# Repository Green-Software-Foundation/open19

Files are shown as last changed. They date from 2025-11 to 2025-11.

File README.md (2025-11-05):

# Open19 V1 Specification

The Open19 specification is a standard for data center rack and server form factors that focuses on standardized power distribution, high-performance networking, and blind-mate connectors. Key features include multiple server "brick" form factors, a modular power shelf, and support for both traditional air-cooling and newer liquid-cooling systems. It allows vendors to choose their own components while ensuring physical compatibility within the rack, promoting choice and innovation. 

- [Open19-V1-Servers-specification](https://github.com/Green-Software-Foundation/open19/blob/v1.0/discussion-docs/Open19_V1_System_Level_Specification.pdf)
- [Open19_V1_System_Level_Specification](https://github.com/Green-Software-Foundation/open19/blob/v1.0/discussion-docs/Open19_V1_System_Level_Specification.pdf)
***
## Key aspects of the Open19 specification:
Brick form factors: The standard defines several independent server "brick" form factors, including half-width 1U, full-width 1U, 2U, and a half-width 2U for GPUs.

***
### Power:
The system uses a modular power shelf that holds vendor-specific power supplies.
The Open19 v2 specification enables higher power delivery (3.5kW per brick) and supports 48V native power, which is more efficient than traditional 12V systems.
Power and data connectors are designed to be "blind-mate," meaning they connect automatically when a brick is installed, simplifying installation.

***
### Networking:
The baseline connectivity is 100 gigabits per second, which can be extended to 200 gigabits per second.
Future versions are designed to support higher speeds.

***
### Cooling:
The standard supports both traditional air-cooling and newer liquid-cooling systems.
Liquid-cooled racks use blind-mate plumbing connections for coolant, making liquid-cooled server installation as easy as air-cooled ones.

***
### Flexibility:
Open19 only specifies the physical and power/network infrastructure, not the internal components like CPUs or RAM. This allows vendors to choose their own processors and other internal hardware, promoting vendor choice.
Vendors can create and protect their intellectual property without sharing designs via an open-source license.

***
**All documentation associated with a project must be licensed under either a Creative Commons Attribution lincense (CC-BY) or, in the case of technical specifications, under a Creative Commons Attribution NoDerivs license (CC-BY-ND)**

***
***
# Open19 V2 Specification

The Open19 V2 specification, published in December 2023 by the Sustainable & Scalable Infrastructure Alliance (SSIA) under the Linux Foundation, introduces significant updates primarily focused on higher power densities, a native 48V DC power solution, and a standardized liquid cooling system. 
***
## Key updates and changes from V1 include:

### Liquid Cooling Standard: 
V2 incorporates a pluggable liquid cooling standard with blind-mate connectors, making the installation of liquid-cooled servers as simple as air-cooled equipment and eliminating external plumbing after initial setup.
***
### Power Distribution: 
The specification moves to a native 48V DC power solution from the 12V DC in V1. This is more efficient for modern data centers and aligns Open19 with other industry standards like OCP, allowing server manufacturers to adopt a single standard.
***
### Increased Power Density: 
The power delivery per "brick" (a half-width 1U server unit) is significantly increased. V1 offered 400W per brick, while V2 increases this capacity to support up to 3.5kW per brick (or 1.6kW per 1RU section), accommodating the demands of next-generation processors and AI workloads.

### Enhanced Connectivity: 
Network bandwidth per server is enhanced, with initial support for 50GbE connectivity per brick, and a path to 200GbE in the future.
***
### Simplified Cabling: 
The design continues to use blind-mate connectors for power and data, further minimizing or eliminating the need for complex, manual cabling at the rear of the rack during server installation.
Backward Compatibility: The new specification maintains the original 19-inch form factor and core principles, allowing for backward compatibility so that V1 servers can still be used in the new V2 system

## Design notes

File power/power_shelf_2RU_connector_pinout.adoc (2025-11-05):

= 2RU Power Shelf connector pinout

In a 2RU power shelf, the following table describes the grouping for four power connector sets. Rows A, B are the bottom RU of a power shelf. Rows C, D are the upper RU of a power shelf. When viewing the rear of the power shelf from the outside, column C1 is on the left and column C16 is on the right.

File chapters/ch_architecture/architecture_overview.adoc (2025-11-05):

ifndef::imagesdir[:imagesdir: ../../images]

ifndef::book[]

endif::[]

= Open19 Architecture Overview

== General

This document will introduce the Open19 V2 architecture, built upon many of the original Open19 principles (referred to as Open19 V1). The significant changes from the V1 specification are:

- Introduction of liquid cooling solutions in both single-phase and two-phase
- Introduction of 48V DC power with no V1 interop
- Increase in differential pairs for high-speed data with support for 56G PAM-4
- Definition of a 4U brick cage

The building blocks can be used to assemble working solutions, which can adapt to site-specific requirements. "Paved path" solutions are detailed in the implementers guide(s).

The only "hard" requirement for Open19 is 1000mm deep 19" racks.

== Background

The Open19 specification defines a consistent mechanical standard for technology delivery. It addresses the operational complexity of standard 19" servers while maintaining an envelop to retain IP. Finally, it de-couples the infrastructure components from the technology allowing for extended life-cycles to meet sustainability goals. Open19 V2 builds on the foundational architecture of the original specification (retroactively termed Open19 V1).

== Requirements

Open19 maintains a minimal set of requirements:

- Commodity EIA/TIA 19" square-hold 4-post rack. The rack is not defined; any EIA/TIA compatible rack able to support the final weight AND at least 1000mm deep can be used.
- 10&#0176;C to 40&#0176;C ambient environment, in line with ASHRAE A1A
- Water supply temperate meeting ASHRAE W27
- Single-phase or three-phase AC power available world-wide in 50/60Hz and 380V HVDC

Open19 V2 explicitly does NOT define a number of areas:

- Rack height, depth, nor width
- Rack level infrastructure including HRU/CDU's, rack coolant manifolds, power strips, and network switches.
- Technology and cooling delivered inside the brick.

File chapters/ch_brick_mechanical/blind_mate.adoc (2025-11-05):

ifndef::imagesdir[:imagesdir: ../../images]
ifndef::brick[:brick: brick]
ifndef::UBrick[:UBrick: Brick]
ifndef::brickplus[:brickplus: brick]
:xrefstyle: full

= Blind mate interfaces

A {brick} is equipped with at least one set of blind mate connectors for receiving +48V DC power and transferring data with an external device, typically a network switch. Introduced in this version is are blind mate connections to facilitate liquid cooling. The connections mate with cable and manifold projections from the rear wall of the cage.

- Power connector: Molex Ten60 PN: 220370-0001 (35A) 22037-0000 (70A), refer to Molex document link:../../power/2203700000psd000_01__4_.pdf[PSD-220370-0000]

- Data connector: Molex 4x8 Impel with guide receptacle PN: 204066-9038 (PCB thickness 2.2-4.1mm), 204066-9138 (PCB thickness 1.0-1.9mm), refer to Molex document link:../../data/2040669001-sdpsd000_02[PSD-204066-9001]

The power connector has two ratings:

- Power: Not-To-Exceed (NTE) 70A at +48V DC
- Power: Not-To-Exceed (NTE) 35A at +48V DC

The ratings shall be coordinated with the power shelf. 35A bricks shall be enabled in 70A capable infrastructure. 70A bricks are keyed to prevent unsafe operation in 35A infrastructure.

ifdef::dhhw,shdw[]
The {brick} may populate a second set of connectors, as required.
endif::[]

ifdef::dhdw[]
The {brick} may populate up to four sets of connectors, as required.
endif::[]

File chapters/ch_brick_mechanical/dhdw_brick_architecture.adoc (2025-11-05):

ifndef::imagesdir[:imagesdir: ../../images]
ifndef::brick[:brick: double high double wide brick]
ifndef::UBrick[:UBrick: Double high double wide brick]
ifndef::brickplus[:brickplus: double high double wide]
:bricktype: dhdw
:dhdw:
:feedcount: 4
:chapter:
:xrefstyle: full

ifdef::standalone[]
:sectnums:
:toc: macro 

= {Ubrick} Mechanical Specification [DHHW]
Linux Foundation Open19 Project
:title-page-background-image: 

toc::[]

<<<
[preface]

include::../book/contributors.adoc[]

<<<

[preface]
== Change log

|===
| Author | Date | Version | Change Details 
| My Truong | Nov 2023 | 2.0 | Liquid-cooled Spec release
| My Truong | Nov 2022 | RC 3 | Power connector move towards liquid cooling cutout 
| My Truong | Oct 2022  | RC2 | Power connector offset correction, 2P liquid cooling connector update 
| My Truong | Sept 2022 | RC1 | 48V DC @70A, 4x8 data connector, liquid cooling 
|===
endif::[]

<<<

ifndef::standalone[]
= {Ubrick} Mechanical Specification [DHDW]

endif::[]
== DHDW {ubrick}

:leveloffset: +1

The DHDW {brickplus} is commonly used as a 2U server form-factor.

<<<

include::../../mechanical/brick/Brick_Dimensions.adoc[]

:leveloffset: -1

<<<

== Mechanical features

:leveloffset: +2

include::retention.adoc[]

include::mechanical_guide.adoc[]

ifdef::liquid[]
include::mechanical_assist.adoc[]
endif::[]

include::mechanical_key.adoc[]

include::pcba.adoc[]

include::materials.adoc[]

include::blind_mate.adoc[]

:leveloffset: -2

=== Weight

The maximum weight of the brick, when equipped with all drives and/or accessories, is 120lbs (54.43kg). This is an increase of 20lbs from V1.

== Connector Pinout

:leveloffset: +2

include::../../power/brick_power.adoc[]

include::../../data/data_connector.adoc[]

include::../../data/ethernet_interop.adoc[]

:leveloffset: -2

<<<
ifdef::liquid[]
== Liquid cooling

:leveloffset: +2

include::brick_liquid_cooling.adoc[]

:leveloffset: -2

<<<
endif::[]
== Design guidance

Design guidance is not a specification requirement. It is simple design guidance that can be implemented to simplify future needs, to meet certification requirements, or satisfy general fit & finish.

=== {UBrick} faceplate guidance 

The faceplate is notched above and below the fastener (See <<#img-dhdw-brick-retention>>). Note that the faceplate can accommodate any type of ports or drives as needed and is not required to be fully perforated.

Screws and/or rivets used to secure the top cover are flush to be under-flush. The vertical edges on the rear of the brick chassis base are coined to break sharp edges.

=== Back panel safety perforation

See below for typical dimensions of the airflow perforation. All dimensions below are critical.

[#img-panel-perforation]
.{UBrick} panel perforation



{sp} +

:leveloffset: +3

include::keepout.adoc[]

:leveloffset: -3

<<<

== Brick performance

:leveloffset: +2

include::../../power/brick_startup.adoc[]

:leveloffset: -2

<<<

ifdef::standalone[]

include::../book/appendix.adoc[]

endif::[]

:!dhdw:
:!feedcount:

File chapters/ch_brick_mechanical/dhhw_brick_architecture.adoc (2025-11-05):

ifndef::imagesdir[:imagesdir: ../../images]
ifndef::brick[:brick: double high half width brick]
ifndef::UBrick[:UBrick: Double high half width brick]
ifndef::brickplus[:brickplus: double high half width]
:bricktype: dhhw
:dhhw:
:feedcount: 2
:chapter:
:xrefstyle: full

ifdef::standalone[]
:sectnums:
:toc: macro 

= {Ubrick} Mechanical Specification [DHHW]
Linux Foundation Open19 Project
:title-page-background-image: 

toc::[]

<<<
[preface]

include::../book/contributors.adoc[]

<<<

[preface]
== Change log

|===
| Author | Date | Version | Change Details 
| My Truong | Nov 2023 | 2.0 | Liquid-cooled Spec release
| My Truong | Nov 2022 | RC 3 | Power connector move towards liquid cooling cutout 
| My Truong | Oct 2022  | RC2 | Power connector offset correction, 2P liquid cooling connector update 
| My Truong | Sept 2022 | RC1 | 48V DC @70A, 4x8 data connector, liquid cooling 
|===
endif::[]

<<<

ifndef::standalone[]
= {Ubrick} Mechanical Specification [DHHW]

endif::[]
== DHHW {ubrick}

:leveloffset: +1

The DHHW {brickplus} is commonly used as a 2U 2N server form-factor.

<<<

include::../../mechanical/brick/Brick_Dimensions.adoc[]

:leveloffset: -1

<<<

== Mechanical features

:leveloffset: +2

include::retention.adoc[]

include::mechanical_guide.adoc[]

ifdef::liquid[]
include::mechanical_assist.adoc[]
endif::[]

include::mechanical_key.adoc[]

include::pcba.adoc[]

include::materials.adoc[]

include::blind_mate.adoc[]

:leveloffset: -2

<<<

== Connector Pinout

:leveloffset: +2

include::../../power/brick_power.adoc[]

include::../../data/data_connector.adoc[]

include::../../data/ethernet_interop.adoc[]

:leveloffset: -2

<<<
ifdef::liquid[]
== Liquid cooling

:leveloffset: +2

include::brick_liquid_cooling.adoc[]

:leveloffset: -2

<<<
endif::[]
=== Weight

The maximum weight of the {brick}, when equipped with all drives and/or accessories, is 60lbs (13.6kg). This is an increase of 10lbs from V1.

=== Design guidance

Design guidance is not a specification requirement. It is simple design guidance that can be implemented to simplify future needs, to meet certification requirements, or satisfy general fit & finish.

=== Brick faceplate guidance 

The faceplate is notched above and below the fastener (See <<#img-dhhw-brick-retention>>). Note that the faceplate can accommodate any type of ports or drives as needed and is not required to be fully perforated.

Screws and/or rivets used to secure the top cover are flush to be under-flush. The vertical edges on the rear of the brick chassis base are coined to break sharp edges.

=== Back panel safety perforation

See below for typical dimensions of the airflow perforation. All dimensions below are critical.

[#img-panel-perforation]
.{UBrick} panel perforation



{sp} +

:leveloffset: +3

include::keepout.adoc[]

:leveloffset: -3

<<<

== Brick performance

:leveloffset: +2

include::../../power/brick_startup.adoc[]

:leveloffset: -2

<<<

ifdef::standalone[]

include::../book/appendix.adoc[]

endif::[]

:!dhhw:
:!feedcount:

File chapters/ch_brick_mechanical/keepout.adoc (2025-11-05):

ifndef::imagesdir[:imagesdir: ../../images]
ifndef::brick[:brick: brick]
ifndef::UBrick[:UBrick: Brick]
ifndef::brickplus[:brickplus: brick]
ifndef::bricktype[:bricktype: shhw]

= Keep-out zones

Keep-out zones are defined in the {brick} surrounding the power connector and liquid cooling interfaces. The liquid cooling keep-out spaces "fly" above the PCB, allowing components to be populated below the connections.

[#img-brick_keep-out_zone]
.{UBrick} keep-out zone



{sp} +

[#img-brick_keep-out_zone_top]
.{UBrick} keep-out zone top view


{sp} +

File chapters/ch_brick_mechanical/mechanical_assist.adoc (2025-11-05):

ifndef::imagesdir[:imagesdir: ../../images]
ifndef::brick[:brick: brick]
ifndef::UBrick[:UBrick: Brick]
ifndef::brickplus[:brickplus: brick]
:xrefstyle: full

== {UBrick} insertion and retention assistance for liquid cooling

For liquid cooling applications, two different mechanical assist for insertion and retention are available in the cage. {UBrick}s can implement features to make use either/both features.

The features are:

- {UBrick} retention standoff, available on both sides in the mechanical guide channel

- Slots, available on both sides of the cage wall

[#img-{bricktype}_brick_mechanical_assist]
.Brick mechanical assistance features in cage



{sp} +

Each feature shall support 100 lbf (445N) force or greater, using the recommended 1.3mm SGCC material.

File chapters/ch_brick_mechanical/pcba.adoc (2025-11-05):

ifndef::imagesdir[:imagesdir: ../../images]
ifndef::brick[:brick: brick]
ifndef::UBrick[:UBrick: Brick]
ifndef::brickplus[:brickplus: brick]
ifndef::bricktype[:bricktype: shhw]

= PCBA

The rear PCBA (Printed Circuit Board Assembly), also referenced as the interposer, provides the +48V DC input power and a data connections. The top of the PCBA is the reference surface, located 6.5mm +/- 0.6mm above the bottom surface of the sheet metal chassis.

ifdef::dhhw,dwdh[]
A second PCBA may be installed at 48.55mm +/- 0.5mm above the bottom surface of the chassis.
endif::[]

[#img-{bricktype}pcba_references]
.PCBA References



{sp} +

[#img-{bricktype}brick-pcb_dimensions]
.{UBrick} PCB dimensions



{sp} +
ifdef::dhhw,dwdh[]
One set of connectors are shown in the image. Two sets are available in a {brick}.
endif::[]

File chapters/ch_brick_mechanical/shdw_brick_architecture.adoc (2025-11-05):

ifndef::imagesdir[:imagesdir: ../../images]
ifndef::brick[:brick: single height double wide brick]
ifndef::UBrick[:UBrick: Single height double wide brick]
ifndef::brickplus[:brickplus: single height double width (SHDW)]
:bricktype: shdw
:shdw:
:feedcount: 2
:chapter:
:xrefstyle: full

ifdef::standalone[]
:sectnums:
:toc: macro 

= {Ubrick} Mechanical Specification [SHDW]
Linux Foundation Open19 Project
:title-page-background-image: 

toc::[]

<<<
[preface]

include::../book/contributors.adoc[]

<<<

[preface]
SSIA Logo

The Sustainable & Scalable Infrastructure Alliance (SSIA) is a community-based organization dedicated to creating, fostering and driving adoption of open standards that increase the efficiencies of the data center and digital infrastructure supply chains.   We enable digital leaders from any sized organization to adopt and deploy advanced and highly efficient rack-level datacenter technologies to increase sustainability, power next-generation workloads and reduce cost and waste, regardless of deployment size or location.  

SSIA members include data center operators, private and public cloud end users, supply chain manufacturers and technology component providers, as well as thousands of individual members active in the cloud, technology, data center and edge ecosystem.

Learn more about joining the Linux Foundation SSI Alliance at http://www.ssia.org/about-us/.

== Change log

|===
| Author | Date | Version | Change Details 
| My Truong | Nov 2023 | 2.0 | Liquid-cooled Spec release
| My Truong | Nov 2022 | RC 3 | Power connector move towards liquid cooling cutout 
| My Truong | Oct 2022  | RC2 | Power connector offset correction, 2P liquid cooling connector update 
| My Truong | Sept 2022 | RC1 | 48V DC @70A, 4x8 data connector, liquid cooling 
|===
endif::[]

<<<
ifndef::standalone[]
= {Ubrick} Mechanical Specification [SHDW]

endif::[]
== SHDW {ubrick}

:leveloffset: +1

The SHDW {brickplus} is commonly used as a 1RU server form-factor.

<<<

include::../../mechanical/brick/Brick_Dimensions.adoc[]

:leveloffset: -1

<<<

== Mechanical features

:leveloffset: +2

include::retention.adoc[]

include::mechanical_guide.adoc[]

ifdef::liquid[]
include::mechanical_assist.adoc[]
endif::[]

include::mechanical_key.adoc[]

include::pcba.adoc[]

include::materials.adoc[]

include::blind_mate.adoc[]

:leveloffset: -2

=== Weight

The maximum weight of the brick, when equipped with all drives and/or accessories, is 60lbs (13.6kg). This is an increase of 10lbs from V1.

<<<

== Connector Pinout

:leveloffset: +2

include::../../power/brick_power.adoc[]

include::../../data/data_connector.adoc[]

include::../../data/ethernet_interop.adoc[]

:leveloffset: -2

<<<
ifdef::liquid[]
== Liquid cooling

:leveloffset: +2

include::brick_liquid_cooling.adoc[]

:leveloffset: -2

<<<
endif::[]
== Design guidance

Design guidance is not a specification requirement. It is simple design guidance that can be implemented to simplify future needs, to meet certification requirements, or satisfy general fit & finish.

=== {UBrick} faceplate guidance 

The faceplate is notched above and below the fastener (See <<#img-shdw-brick-retention>>). Note that the faceplate can accommodate any type of ports or drives as needed and is not required to be fully perforated.

Screws and/or rivets used to secure the top cover are flush to be under-flush. The vertical edges on the rear of the brick chassis base are coined to break sharp edges.

=== Back panel safety perforation

See below for typical dimensions of the airflow perforation. All dimensions below are critical.

[#img-panel-perforation]
.{UBrick} panel perforation



{sp} +

:leveloffset: +3

include::keepout.adoc[]

:leveloffset: -3

<<<

== Brick performance

:leveloffset: +2

include::../../power/brick_startup.adoc[]

:leveloffset: -2

<<<

ifdef::standalone[]

include::../book/appendix.adoc[]

endif::[]

:!shdw:
:!feedcount:

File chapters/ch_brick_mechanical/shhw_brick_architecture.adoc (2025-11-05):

ifndef::imagesdir[:imagesdir: ../../images]
ifndef::brick[:brick: brick]
ifndef::UBrick[:UBrick: Brick]
ifndef::brickplus[:brickplus: brick]
:bricktype: shhw
:shhw:
:feedcount: 2
:chapter:
:xrefstyle: full

ifdef::standalone[]
:sectnums:
:toc: macro 

= {Ubrick} Mechanical Specification [SHHW]
Linux Foundation Open19 Project
:title-page-background-image: 
// :page-foreground-image: 

toc::[]

<<<
[preface]

include::../book/contributors.adoc[]

<<<

[preface]
SSIA Logo

The Sustainable & Scalable Infrastructure Alliance (SSIA) is a community-based organization dedicated to creating, fostering and driving adoption of open standards that increase the efficiencies of the data center and digital infrastructure supply chains.   We enable digital leaders from any sized organization to adopt and deploy advanced and highly efficient rack-level datacenter technologies to increase sustainability, power next-generation workloads and reduce cost and waste, regardless of deployment size or location.  

SSIA members include data center operators, private and public cloud end users, supply chain manufacturers and technology component providers, as well as thousands of individual members active in the cloud, technology, data center and edge ecosystem.

Learn more about joining the Linux Foundation SSI Alliance at http://www.ssia.org/about-us/.

== Change log

|===
| Author | Date | Version | Change Details 
| My Truong | Nov 2023 | 2.0 | Liquid-cooled Spec release
| My Truong | Nov 2022 | RC 3 | Power connector move towards liquid cooling cutout 
| My Truong | Oct 2022  | RC2 | Power connector offset correction, 2P liquid cooling connector update 
| My Truong | Sept 2022 | RC1 | 48V DC @70A, 4x8 data connector, liquid cooling 
|===
endif::[]

<<<

ifndef::standalone[]
= {Ubrick} Mechanical Specification [SHHW]

endif::[]
== SHHW {ubrick}

//ifdef::standalone[]
//ifeval::[{doctype} == "article"]
//
//
//
//endif::[]
//endif::[]

:leveloffset: +1

The SHHW {brickplus} form-factor is a half-wide 1RU commonly used as the basis of 2U 4-node designs.

<<<

include::../../mechanical/brick/Brick_Dimensions.adoc[]

:leveloffset: -1

<<<

== Mechanical features

:leveloffset: +2

include::retention.adoc[]

include::mechanical_guide.adoc[]

ifdef::liquid[]
include::mechanical_assist.adoc[]
endif::[]

include::mechanical_key.adoc[]

include::pcba.adoc[]

include::materials.adoc[]

include::blind_mate.adoc[]

:leveloffset: -2

=== Weight

The maximum weight of the {brick}, when equipped with all drives and/or accessories, is 30lbs (13.6kg). This is an increase of 5lbs from V1.

== Connector Pinout

:leveloffset: +2

include::../../power/brick_power.adoc[]

include::../../data/data_connector.adoc[]

include::../../data/ethernet_interop.adoc[]

:leveloffset: -2

<<<
ifdef::liquid[]
== Liquid cooling

:leveloffset: +2

include::brick_liquid_cooling.adoc[]

:leveloffset: -2

<<<
endif::[]
== Design guidance

Design guidance is not a specification requirement. It is simple design guidance that can be implemented to simplify future needs, to meet certification requirements, or satisfy general fit & finish.

=== {UBrick} faceplate guidance 

The faceplate is notched above and below the fastener (See <<#img-shhw-brick-retention>>). Note that the faceplate can accommodate any type of ports or drives as needed and is not required to be fully perforated.

Screws and/or rivets used to secure the top cover are flush to be under-flush. The vertical edges on the rear of the brick chassis base are coined to break sharp edges.

=== Back panel safety perforation

See below for typical dimensions of the airflow perforation. All dimensions below are critical.

[#img-panel-perforation]
.{UBrick} panel perforation



{sp} +

:leveloffset: +3

include::keepout.adoc[]

:leveloffset: -3

<<<

== Brick performance

:leveloffset: +2

include::../../power/brick_startup.adoc[]

:leveloffset: -2

<<<

ifdef::standalone[]

include::../book/appendix.adoc[]

endif::[]

:!shhw:
:!feedcount:

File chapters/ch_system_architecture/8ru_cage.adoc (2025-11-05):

ifndef::imagesdir[:imagesdir: ../../images]
:plusmn: &#177;

= 8RU Cage detail

The 8RU cage is designed to be installed in a standard EIA/TIA 19-inch rack. The dimensions of cage allow for proper mating of all blind-mate interfaces on bricks. 

== 8RU Cage dimensions

[#image-8RU-cage-depth]
.8RU Open19 V2 cage depth



{sp} +

[#image-8RU-cage-side]
.8RU Open19 V2 cage depth side view



{sp} +

[#image-8RU-cage-rear]
.8RU Open19 V2 cage rear



{sp} +

== 8RU Cage partition

The 8RU cage is built around a 2RU section, 84.7{plusmn}0.25mm tall and 443.80{plusmn}0.25mm wide. This section can accommodate a single DHDW brick or two SHDW bricks.

== 8RU Cage Center divider (CD) partition

With a center divider (CD) installed, each section can accommodate one of the following combinations:

- One to four SHHW bricks
- One or two DHHW bricks

Dropped from the V2 spec is one DHHW plus one or two SHHW bricks.

With the center divider installed, each 2RU section is 84.7{plusmn}0.25mm tall and 215.02{plusmn}0.25mm.

== 8RU Cage Center Divider (CD)

The Center Dividier (CD) is installed to support SHHW and DHHW bricks. Mechanical retention of the divider should be integrated into the divider. The Open19 V1 specification provides details on a reference CD design.

[#image-8RU-cage-center-divider]
.Open19 V2 cage Center Divider



{sp} +

== Horizontal divider

The horizontal divider partitions the cage in 2RU sections. Horizontal dividers shall have strips to provide a low-friction surface and minimize metal-on-metal contact.

[#image-horizontal-divider]
.Open19 Cage horizontal divider



{sp} +

== Load capacity

The 8RU cage can accommodate 16 bricks with a maximum 30lbs (13.6kg) each.

== Brick Retention

Each side wall contains eight (8) Southco D9-63-11 self-clinching receptacles that secure bricks with quarter-turn fasteners as the primary means of retention. 

[#image-cage-retention-detail]
.Cage retention quarter turn fastener locations



{sp} +

For liquid cooling applications, additional features are available to provide sufficient mechanical assistance to overcome total connector forces. These features are detailed in the liquid cooling section.

== Blind mate cutouts

The rear wall of the 2RU space provides consistent cutouts for the cooling, data, and +48V DC power cables. 

[#img-cage-panel-cutout]
.Cage rear panel cutouts



{sp} +

[#img-cage-panel-cutout-detail]
.Cage rear panel cutout details



{sp} +

== Keying stops

Keying stops are provided in the right and left rear corners of each cage section. These stops (bent tabs) interface with notches in the brick sides to provide a positive stop during brick insertion and prevent over insertion or possible connector damage. They are positioned as shown.

[#image-keying-stops]
.Brick keying stops



{sp} +

== Mounting ear locations

The primary cage mounting ear is positioned 40mm behind the front face of the cage side wall. Two additional positions are provided, 100mm and 200mm from the mounting ear surface to the front face of the cage side wall.

[#image-mounting-ear-locations]
.Cage mounting ear locations



{sp} +

These recommended locations are design guidance from V1 and may be adapted for specific applications.

== Cage mounting rails

Rack rails are the primary mechanism to support the cage during installation and use. A hook facilitates rail installation in square hole four-post racks. Rails should not protrude into the bottom surface of the cage.

[#image-rack-rails]
.Cage rack rails



{sp} +

Installing rails should accommodate a range of rack post spacing from 28.5” to 36.0”. For other types of racks, a modified version of the rail can be developed.

The rails should support:
 
- Bare cage installed in a rack during shipping – cage mounting ear screws must secure cage in the rack
- Bare cage installed in a data center rack – cage mounting ear screws not installed
- Fully populated cage during installation into a rack
- Fully populated cage during use – cage mounting ear screws must secure cage in the rack

== Material

The 8RU cage is designed to be constructed of SGCC sheet metal. 1.2mm (19 gauge steel) is the primary thickness used throughout, with 0.8mm and 1.6mm used on some stiffener panels, 1.88mm used for the cage mounting brackets and 2.38mm for the rails.
 
The data and power connectors are built with a 1.20mm +/- 0.05mm expectation for latching mechanism. Panel thickness may be altered as required; the area surrounding the connectors shall remain 1.20mm +/- 0.05mm and shall maintain the 6.23mm face-to-face panel spacing.

Two molded plastic parts are used on the cage assembly. These parts are identical to the V1 design.

Sliders are used on the cage walls and center dividers to support bricks. Two sliders are used per brick side, 64 sliders are used in a cage fully populated with center dividers. Sliders are molded in Ultem 1000 resin.

[#image-cage-slide]
.Cage slide



{sp} +

Dowel pin inserts are used in ten (10) places in each center divider. These parts are molded in Ultem 1000 resin.

[#image-cage-divider-mould]
.Cage divider



{sp} +

Low-friction strips used on the horizontal dividers are made of black FR700-701 polycarbonate sheet with 3M 467 PSA applied.

ifdef::private[]

== Detailed drawings

Detailed drawings of all the features are in <<8RU Cage detailed drawings>>.

endif::[]

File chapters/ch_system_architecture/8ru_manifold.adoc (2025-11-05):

ifndef::imagesdir[:imagesdir: ../../images]

= 8RU Cage Manifold

== Attachment points

The 8RU cage provides consistent attachment points for both single-phase and two-phase liquid cooling manifolds. Two PEM nuts are available in every brick location.

[#img-manifold-attachment-detail]
.Manifold attachment



{sp} +

[#img-manifold-bracket-left]
.Sample left manifold bracket



{sp} +

[#img-manifold-bracket-right]
.Sample right manifold bracket



{sp} +

== Manifold

The liquid cooling manifold is not interoperable between single-phase and two-phase, by design. The bricks provide a blind-mate projection from the brick into the liquid cooling manifold. 

== Single-phase manifold
:leveloffset: +2

include::../../cooling/single_phase/1p-spec_manifold.adoc[]

:leveloffset: -2

== Two-phase manifold
:leveloffset: +2

include::../../cooling/two_phase/2p-spec_manifold.adoc[]

:leveloffset: -2

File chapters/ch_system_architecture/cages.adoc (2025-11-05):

ifndef::imagesdir[:imagesdir: ../../images]

= Open19 V2 Cages

Open19 V1 defined a base building element, the brick cage, for building the Open19 infrastructure. The cage is a completely passive element able to receive any Open19 V2 compliant device. The brick definition governs cage dimensions (and visa versa). The cages are re-configurable to accommodate any Open19 V2 compliant brick.

Open19 V2 introduces cut-outs and attachment features for liquid cooling manifolds, expanded cut-out for the larger blind-mate data connector, and expanded cut-out for the new power connector.

== Cage modularity 

Cages are designed to support all defined bricks. The current definition of bricks use a 2RU maximum format, enabling the following brick form-factors in each 2RU section:

- (4) Single high Brick - Half-width 1RU [SHHW]
- (2) Double high bricks - Half-width 2RU [DHHW]
- (2) Single high bricks - double-width 1RU [SHDW]
- (1) Double high brick - double-width 2RU [DHDW]

The design package supports two cage form-factors, 8RU and 4RU. Additional cage groupings can be synthetically formed from these units, including the 12RU from the V1 spec. This enables extremely small deployments of 6RU (4RU cage + 2RU power shelf) with no upper limit.

[#image-8RU-cage]
.8RU Open19 V2 cage front



{sp} +

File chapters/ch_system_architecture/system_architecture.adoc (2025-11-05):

ifndef::imagesdir[:imagesdir: ../../images]

:chapter:
:xrefstyle: full

ifdef::standalone[]
:sectnums: 
:toc: macro

= Open19 System Specification
Linux Foundation Sustainable Scalable Infrastructure Alliance
:title-page-background-image: 

toc::[]

<<<
[preface]

include::../book/contributors.adoc[]

<<<

[preface]
SSIA Logo

The Sustainable & Scalable Infrastructure Alliance (SSIA) is a community-based organization dedicated to creating, fostering and driving adoption of open standards that increase the efficiencies of the data center and digital infrastructure supply chains.   We enable digital leaders from any sized organization to adopt and deploy advanced and highly efficient rack-level datacenter technologies to increase sustainability, power next-generation workloads and reduce cost and waste, regardless of deployment size or location.  

SSIA members include data center operators, private and public cloud end users, supply chain manufacturers and technology component providers, as well as thousands of individual members active in the cloud, technology, data center and edge ecosystem.

Learn more about joining the Linux Foundation SSI Alliance at http://www.ssia.org/about-us/.

== Change log

ifdef::liquid[]
|===
| Author | Date | Version | Change Details 
| My Truong | Nov 2023 | 2.0 | Public Spec release
|===
endif::[]
ifndef::liquid[]
|===
| Author | Date | Version | Change Details 
| My Truong | May 2023 | 2.0 | Air-cooled Spec release
|===
endif::[]

endif::[]

<<<
[preface]
include::../book/definitions.adoc[]

<<<
:leveloffset: +1

include::cages.adoc[]

:leveloffset: -1

:leveloffset: +2

include::8ru_cage.adoc[]

:leveloffset: -2

== Liquid cooling support

:leveloffset: +1

include::../ch_brick_mechanical/mechanical_assist.adoc[]

:leveloffset: -1

=== Manifold attachments

The 8RU cage provides consistent attachment points for both single-phase and two-phase liquid cooling manifolds. PEM nuts are available in every brick location.

[#img-cage-manifold-attachment]
.Cage manifold attachment



{sp} +

ifdef::liquid[]
:leveloffset: +2

include::8ru_manifold.adoc[]

:leveloffset: -2

:leveloffset: +2

include::../../cooling/facility_temp.adoc[]

:leveloffset: -2
endif::[]

== Open19 V2 Cable System Specification

=== General

The Open19 platform simplifies installation with blind-mate data and power interfaces. To facilitate inter-operability, aspects of the power shelf, brick, and data cable assemblies shall be defined. The cable systems are all completely passive. Components inheriting existing specifications (eg: SFP, QSFP, QSFP-DD) shall be compliant with the industry definitions.

:leveloffset: +2

include::brick_power_assembly.adoc[]

:leveloffset: -2

:leveloffset: +2

include::brick_data_assembly.adoc[]

:leveloffset: -2

== Environmental Requirements

The Open19 platform can operate in any data center environment with no special restrictions nor requirement. The two environmental requirements are:

- Ambient air temperature  of 10-40&#0176;C at sea-level to 1000m elevation

- Unobstructed front and back flow

Noted that while an enclosed rack is also supported for the Open19 platform, the required airflow per disaggregated component in the platform needs to be reviewed separately in case of obstructed airflow.

:leveloffset: +1

include::appendix_system_architecture.adoc[]

:leveloffset: -1

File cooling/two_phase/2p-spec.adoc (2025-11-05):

ifndef::imagesdir[:imagesdir: ../../images/]

= Dielectric two-phase cooling solution

include::2p-spec_connectors.adoc[leveloffset=1]

== Connector mounting polarization

Cage manifolds shall have body (female) blind mate connectors. Bricks shall have insert (male) blind-mate connectors. When viewed from rear of the brick, vapor connection shall be located at the right position. Liquid connection shall be located at the left position.

[#image-brick-polarization]
.Brick liquid supply and Vapor return


{sp} +

== Brick panel detail

* The connectors on the brick side are panel mount with plastic hose connection
** Mate connection type: Blind mate (non-latched).
** G 1/4" male thread for the liquid side - needs to add a tube adaptor for 6mm OD tube (for example reference- PARKERS FEMALE STUD FITTING WITH BSPP FEMALE THREAD 6814 06 13)
** G 1/2" thread for the vapor side- needs to add a tube adaptor for 12mm OD tube (for example reference- PARKERS FEMALE STUD FITTING WITH BSPP FEMALE THREAD 6814 12 21)
* The connectors on the manifold side are parallel male thread
** Mate connection type: Blind mate (non-latched).
** G 1/4” for the liquid side
** G 1/2" for the vapor side

== Vapor connector ==

The vapor connector pressure drop influences the saturated coolant temperature. It causes a slight increase to saturation temperature and by that effects the cooling performances.

The CPC BLQ6 has a nominal diameter of 3/8 inch connector gives a max increase of 4.2°C at 3.5kW (0.24 bar pressure drop).

[#image-two-phase-BLQ6]
.CPC BLQ6 series connector pressure drop vs. power dissipation


{sp} +

== Liquid connector ==

The liquid connector should supply max flow of 1 l/m to support the max power dissipation of 3.6 kW. The max recommended velocity of the system liquid lines is 2.5 m/s. This requires a Nominal diameter larger than 3mm.

The CPC BLQ4 Series connector has a nominal diameter of 1/4 inch that exceeds the above requirement.

include::2p-spec_connectors_detail.adoc[offsetlevel=2]

include::2p-spec_manifold.adoc[leveloffset=2]

include::2p-spec_brick_detail.adoc[leveloffset=2]

= BLQ6 Spec

Coupling material: Aluminum, anodized

Plug material: Aluminum, anodized

Valve: Polysulfone

Seals: EPDM

Flow Coefficient: Cv ~ 2.2

Pressure Range: Vacuum to 120 psi, 8.3 bar

Operating Temperature: 0°F to 240°F (-17°C to 115°C)

[#image-BLQ6-performance-spec]
.BLQ6 performance spec


{sp} +

= BLQ4 Spec

Coupling material: Brass, Chrome plated

Plug material: Brass, Chrome plated

Valve: Polysulfone

Seals: EPDM

Flow Coefficient: Cv ~ 1.3

Pressure: Vacuum to 120 psi, 8.3 bar

Temperature: 0°F to 240°F (-17°C to 115°C)

[#image-BLQ4-performance-spec]
.BLQ4 performance spec


{sp} +

= Closing force

[#image-BLQ6-performance-spec]
.BLQ6 performance spec


{sp} +

BLQ6 closing force is 40N without pressure effect and 65N at 1.85 barg vapor pressure (happens @ Tsat=70°C)

[#image-BLQ4-performance-spec]
.BLQ4 performance spec


{sp} +

BLQ4 closing force is 40N without pressure effect and ~60N at 3 barg liquid pressure (extreme conditions).

= Tested example solution

Vapor connection:

The vapor connection type are two 1" Tri-clamp Ferrule connection. From the manifold side- the fittings are welded into the lower and upper parts of the manifold.

Vapor tubing- Shall be stainless steel corrugated tubes type.

Liquid connection:

The liquid connection shall be with a 1/2" Tri-clamp Ferrule connection. the left-lower part (looking from the back of the cage).

Liquid tubing: Shall be stainless steel corrugated tubes type.

[#image-2P-8RU-manifold rear]
.8RU manifold, rear view


{sp} +

[#image-2P-8RU-manifold front]
.8RU manifold, front view



{sp} +

[#image-2P-full-solution]
.Example full solution



{sp} +

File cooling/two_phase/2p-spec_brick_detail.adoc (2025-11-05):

ifndef::imagesdir[:imagesdir: ../../images/]

= Two-phase brick side connector locations =

Using the right-side panel of the brick as a reference, the Vapor return connector on the brick should be 31.85mm in the x direction and 20.73 upwards in the y direction.

ifdef::shhw[]

[#image-brick-connector-location]
.Brick side connectors locations


endif::[]

ifdef::shdw[]

[#image-brick-connector-location]
.Brick side connectors locations


endif::[]

ifdef::dhhw[]

[#image-brick-connector-location]
.Brick side connectors locations


endif::[]

ifdef::dhdw[]

[#image-brick-connector-location]
.Brick side connectors locations


endif::[]

= Two-phase offset depth =

The mating surface of the brick side connector sits xx mm behind (outside) the outer edge of the back plane of the brick. Specifying this dimension ensures the server manufacturer and manifold/cage side implementor have a consistent location where the connectors must meet to ensure full mating and thereby full flow.

The reference mating surfaces of each connector are highlighted below along with a drawing showing the specified dimension.

[#image-BLQ4-insert-mating-surface]
.Mating surface BLQ4 insert


{sp} +

[#image-BLQ4-body-mating-surface]
.Mating surface BLQ4 body


{sp} +

[#image-BLQ6-insert-mating-surface]
.Mating surface BLQ6 insert



{sp} +

[#image-BLQ6-body-mating-surface]
.Mating surface BLQ6 body


{sp} +

[#image-BLQ4-rear-panel-offset]
.Offset from cage back panel to BLQ4 connector mating interface


{sp} +

[#image-BLQ6-rear-panel-offset]
.Offset from cage back panel to BLQ6 connector mating interface



The BLQ4 & BLQ6 connectors must be within ±1.5mm of this engaged state to achieve full flow.

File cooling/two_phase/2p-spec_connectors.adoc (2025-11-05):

ifndef::imagesdir[:imagesdir: ../../images/]

= Two-phase connector selection

The two-phase cooling solution shall use the CPC BLQ family of interfaces.

== On brick side

[#image-blq4-insert]
.Liquid - CPC BLQ4 series insert P/N BLQ4D47004PROTO (chrome plated brass) or P/N 4649800PROTO (Aluminum)


{sp} +

[#image-blq6-insert]
.Vapor - CPC BLQ6 series insert P/N 4650000PROTO (chrome plated brass)



{sp} +

== On the Manifold side

[#image-blq4-body]
.Liquid - CPC BLQ4 series body P/N BLQ4D31004PROTO (chrome plated brass) or P/N  4649900PROTO (Aluminum)



{sp} +

[#image-blq6-body]
.Vapor - CPC BLQ6 series body P/N 4650200PROTO (chrome plated brass)



{sp} +

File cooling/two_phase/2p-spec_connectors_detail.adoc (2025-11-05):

ifndef::imagesdir[:imagesdir: ../../images/]

= Two-phase connector mounting polarization 

Cage manifolds shall have body (female) blind mate connectors. Bricks shall have insert (male) blind-mate connectors. When viewed from rear of the brick, vapor connection shall be located at the right position. Liquid connection shall be located at the left position.

ifdef::shhw[]

[#image-brick-polarization]
.Brick liquid supply and Vapor return


{sp} +

endif::[]

ifdef::shdw[]

[#image-brick-polarization]
.Brick liquid supply and Vapor return


{sp} +

endif::[]

ifdef::dhhw[]

[#image-brick-polarization]
.Brick liquid supply and Vapor return


{sp} +

endif::[]

ifdef::dhdw[]

[#image-brick-polarization]
.Brick liquid supply and Vapor return


{sp} +

endif::[]

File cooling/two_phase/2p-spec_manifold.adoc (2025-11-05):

ifndef::imagesdir[:imagesdir: ../../images/]

= Two-phase manifold specified dimensions =

The x-direction from centerline to centerline of connectors in the same U is 27.0mm. The y-direction from centerline to centerline of connectors in the same 2U space of the cage is 42.05mm. The vertical spacing between connectors in separate but adjacent 2U spaces is 46.05mm (to account for the sheet metal thickness in the cage).

[#image-manifold-connector-spacing]
.Manifold and connectors location dimensions (from front)



{sp} +

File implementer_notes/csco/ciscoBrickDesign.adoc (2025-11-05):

= Desired Cisco Brick Architecture

Cisco is pursuing an overall architecture of as near as reasonable a _Net Zero_ architecture in our equipment and services as possible.  Our project also has a design model that favors an increased blast radius, and scale out, _vs._ scale up unless application demands can not be met in a scale out architecture.

With that in mind, we have a few design guidelines for our Open19v2 system design.  They are similar to, but not directly matching the similar Equinix requirements.  For a deeper understanding of our networking requirements, please see the [Network Switching Architecture](Cisco Network Switching Architecture section).

Networking:: All bricks *MUST* support at a minimum, 2x 50GE links on the brick-side Impel connector.  Bricks *MAY* support either 4x 50GE or 2x 100GE.  Within an eighteen to twenty-four month horizon, this may become a hard requirement.

CPU & Memory:: All bricks *SHOULD* support single-socket deployments that support high core-count CPUs.  All bricks *SHOULD* support between eight and sixteen GB of RAM per physical core for multi-threaded architectures, and four and sixteen GB of RAM per physical core for single-threaded CPU architectures.

CPU Architecture:: Cisco is immediately interested in deploying x64 and aarch64 architectures.

Voltage:: Cisco is interested in +48vDC native motherboards as soon as they can reasonably be produced.

Storage:: Cisco's desire is for most bricks to use E1S-format storage.  This storage does not need to be front-panel accessible (see cooling).

Cooling::  Much like Equinix, Cisco's requirement is that bricks *MUST NOT* exhaust more than 400w to 500w of heat via air cooling.  All other heat must be rejected via a liquid cooling system.  All bricks *SHOULD* have the capability to reject all heat load via a liquid cooling loop, as soon as practical.

== A Further Note on Cooling

Cisco is potentially interested in a _flooded_ brick design where the brick is cooled by having the working volume of the brick sealed, and single phase coolant pumped into/out of the brick.  This is one of the drivers for the storage not being front-panel accessible.  This does need design work, and Cisco is interested in working with interested parties to develop a solution for this requirement.

During the development of the Open19v2 brick physical specification development, an additional 6 Lbs of weight margin was added to the brick footprint to account for the density of most single phase coolants.

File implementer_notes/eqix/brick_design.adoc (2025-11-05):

== Open19 Bricks designed for Equinix
=== 400W Thermal constrains
Open19 V2 bricks designed for Equinix shall not dissipate more than 400W of power into air per 1U 1/2W brick. Any brick design >400W shall reject the heat into a liquid cooling solution. 

==== Motivation
The primary motivation for this design requirement is: A fully loaded rack of 64 bricks can deliver 25.6kW of heat into the air. This is the limit of a reasonable air-cooling density design for a data center without auxillary assistance (cooler doors, point-of-load cooling, etc.) 

Secondary motivations are: Allowing existing brick designs to "retrofit" into V2 with some power converter work.

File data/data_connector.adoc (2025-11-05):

ifndef::imagesdir[:imagesdir: ../images]

= Data Connector

The data connector is rated for 56G PAM4 with an air dielectric. Variations of cables deliver different lane counts, data rates, and physical interfaces. In the reference Ethernet implementation, the data connector pinout explicitly supports a dedicated 10/100/1000Base-T management port, four 25G NRZ/50G PAM4 lanes. Optionally, a single QSFP-DD or two QSFP interfaces are supported.

[#image-{bricktype}Impel_ISO]
.Impel Connector with guide feature



{sp} +

[#image-{bricktype}Impel_Mated]
.Impel Mated connector with cable backshell



{sp} +

The data connector pinout is defined in the <<Appendix>>

There is no attempt to support 50G (2x25G NRZ) nor 50G (1x50G NRZ).

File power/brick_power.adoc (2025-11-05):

ifndef::imagesdir[:imagesdir: ../images]
ifndef::brick[:brick: brick]
ifndef::UBrick[:UBrick: Brick]
ifndef::brickplus[:brickplus: brick]
:xrefstyle: full

= {UBrick} power connector

The {brick} blind-mate power connector for receiving 48V DC (51V nominal) power from the power shelf. The connector mates with the power cable connector projected from the brick cage wall.

Two variations of the {brick} connector exist, with different Not-to-exceed (NTE) ratings:

- 35A Power Connector: Molex 2203700001 (NTE 35 AMPS) No Key
- 70A Power Connector: Molex 2203700000 (NTE 70 AMPS) Keyed

[#img-{bricktype}power-connector-pins]
.Power connector supply/return definition
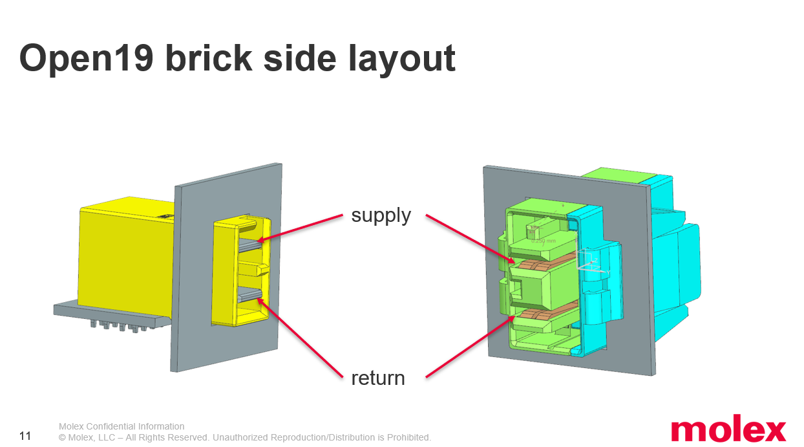
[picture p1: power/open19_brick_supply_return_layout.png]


{sp} +

[#image-{bricktype}power-connector-footprint]
.Power connector footprint definition


{sp} +

Connector drawings are available: link:2203700000psd000_03.pdf[Molex Brick power connector]

= {Ubrick} critical dimensions

The {brick} power connector has a critical dimension for the projection from the brick panel. Spacing between panels is 6.23mm. The power connector shall be proud of the panel 4.40mm.

[#img-{bricktype}brick-power-critical_dimensions]
.Power connector critical dimensions


{sp} +

= {UBrick} voltage

Open19 V2 power shares Open Compute ORV3 power characteristics. Open19 bricks shall safely operate in the DC range 48-52V and shall remain functional when exposed to 0-54V. The power rail shall not exceed 52.5V for more than 200mS. DC voltage shall never exceed 54V.

- Operating range: 48-52V
- NTE voltage: 54V
- Max voltage: <=52.5V for <200mS

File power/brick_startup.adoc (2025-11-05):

ifndef::imagesdir[:imagesdir: ../images/]

= Brick electrical startup behavior

In order to safely operate the power shelf, we define the following characteristics for brick startup behavior.

[#img-serverstartup]
.Server startup electrical characteristics


{sp} +

These values are per connector feed from a power shelf. 

ifdef::shdw,dhhw[]
Two power connectors are available for use.
endif::[]

ifdef::dhdw[]
Four power connectors are available for use.
endif::[]

- Min start-up voltage: +44V DC
- Max input capacitance per brick feed: <=1000uF
- Max server current at start-up voltage: 70A
- Ramp time: Follow Intel CRPS spec: ramp time 10-70msec, slew rate 0.5V/msec

link:https://www.intel.com/content/dam/www/public/us/en/documents/guides/power-supply-design-guide-june.pdf[]

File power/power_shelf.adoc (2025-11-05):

= Power shelf

Open19 V2 aligns with the OCP ORV3 power shelf and power characteristics on the +48V DC output. The departures from the OCP ORV3 specification are outlined in this document.

== Power output

The power shelf shall supply a touch-safe/ring-safe interface with per output safety and control to bricks. This is delivered with a consistent power cable assembly in either a 35A or 70A current-carrying SKU. 

== Safety mechanisms & control

Each output to bricks shall be "safety fused" at 35A or 70A, properly coordinated with the cable assembly installed. Each output shall have on/off ability under software control. Over-current protection shall have safe defaults that may be over-ridden by software.

== Power output connector

The power shelf shall use a consistent power connector for power distribution to bricks. The shelf connectors are Molex Open19 Power shelf recepticle housing, document number link:2203680000_sd.pdf[2203680000]. The pinout is defined in the link:Open19V2_Power_Connector_Brick_Map.pdf[Open19V2 Power Connector Brick Map] document.

== Output grounding

The power outputs shall be isolated from the chassis ground.

== Controller

The controller shall be responsible for output control, power on sequencing, and monitoring of control points. A reference implementation of control software based on the Linux Foundation OpenBMC implementation shall be made available. 

Multiple controllers may be implemented.

== Controller Network interface

The controller shall have an 10/100/1000Base-T interface. Multiple network interfaces per controller may be available. 

== Reset buttons and LED's

Each controller should have a reset button and LED to indicate the status of the controller. The following color scheme can be used to indicate controller states:

- LED off: Faulty controller
- Orange LED: Controller booting
- Green LED: Controller booted and active
- Red LED: Control system faulty post-boot

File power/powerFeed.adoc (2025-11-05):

=== Power Shelf Infeed

The power shelf shall support the following single-phase, three-phase, and 380V HVDC commonly available world-wide:

[%header, cols="6*"]
|===
| AC/DC type | Min | Nominal | Max | Units | Notes

| AC Low-line (per phase) | 90 | 100 - 120 | 132 | VAC | 3W+N+PE/3W+PE
| AC High-line (per phase) | 180 | 200-240 | 264 | VAC | 3W+PE
| AC Low-line (phase-to-phase) | 155 | 172-208 | 229 | VAC | 3W+PE
| AC High-line (phase-to-phase) | 311 | 346-415 | 457| VAC | 3W+N+PE
| AC Input frequency | 47 | 50/60 | 63 | Hz | - 
| HVDC Input | 192 | 240/380 | 400 | VDC | -

|===

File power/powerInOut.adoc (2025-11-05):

== Power Scope

The V2 specification departs from the V1 +12V DC and introduces +48V DC (+50V nominal) to each brick, in order to address industry trends. The V2 brick power connector is mechanically incompatible with V1, by design.

Areas out of scope:

- Energy storage systems (ESS)

include::powerFeed.adoc[]

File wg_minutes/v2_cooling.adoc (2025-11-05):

= Cooling working group

== 2022 Feb 3

No call for Lunar New Year

== 2022 Jan 27
=== Attendees
* Doug Asay, Equinix
* Erin McCann, Schneider Electric
* My Truong, Equinix
* John Leung, Inspur
* Julian Shui, Delta
* Mahyar Fotovatjah, ASUS
* Mealy Huang, Inspur
* Paul Chen, ASRock Rack
* Roy Grantham, Vertiv
* Samuel Cheung, ASUS
* Spike Lin, Inspur
* Suresh Pichai, Equinix
* Bob Wu, Inspur
* Dexter Tseng, Inspur
* Weishi Sa, ASRock Rack
* Claudia Chen, Inspur
* Peter Panfil, Vertiv
* Shahar Belkin, ZutaCore
* Brandy Bengtson, ZutaCore
* Mac Liu, CPC
* Nigel Gore, Vertiv
 
=== Discussion
* Blind mate connection for single-phase
* Locking mechanism and retention force
* Alignment-- gather and float. Is there enough for the brick?
 
* Veriv shared images of the rack with manifolds
* Schneider Electric is proposing CPC BLQ6 for single-phase connections
 
ACTION: Schneider Electric (Erin) Keep out zone inside the brick for single phase 

ACTION: Define a locking/retention mechanism

ACTION: Schneider Electric (Erin) will have final models
 
* Cooling call will be suspended for two weeks to observe Lunar New Year. Calls will resume Feb 17.

== 2022 Jan 20

=== Opens
Brick/cage cut out
Keep out zones internal to brick
Attachment points of bracket to cage standardized
Maximum available distance between back of cage to rack rear door
Air flow/area available for hot air to leave the server
 
=== Discussion
* ZutaCore supplied suggestions for cutout
* See below the preliminary dimensions for the ZutaCore 2PLC blind mate.
* The opening on the brick back panel and the cage back panel should be: 58x38mm
* The keep out zone for the brick is as follows:
* The dimensions are:
** The server cube with the blind mate connectors is 55X35 mm 
** As the cube is connected to the brick with sliders the cut out in the brick and cage needs to be 3mm bigger than the cube = 58x38 mm 
** The 78mm is the area needed on the brick wall including the sliders that hold the cube to the brick.
 
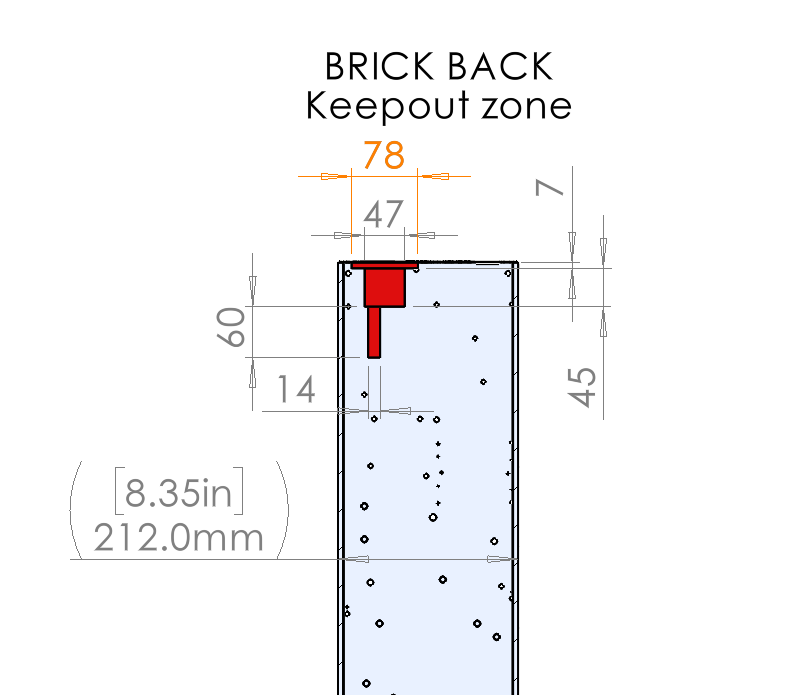
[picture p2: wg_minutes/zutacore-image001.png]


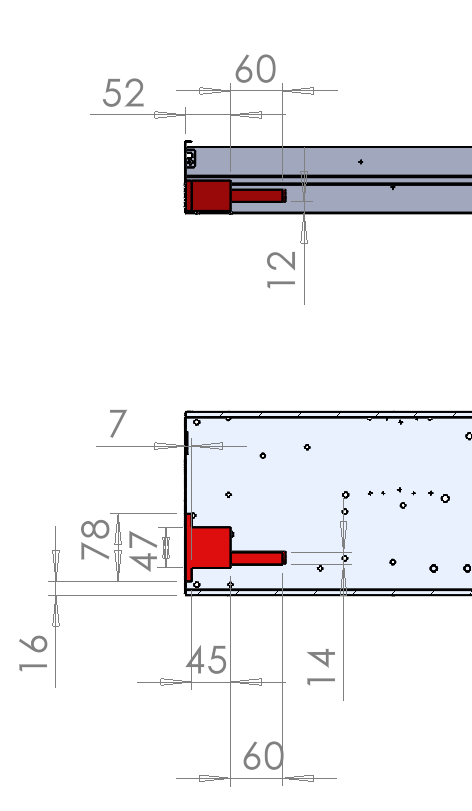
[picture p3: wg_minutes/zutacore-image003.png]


==== To finalize in next call (Jan 27)
Cutout on brick is 58x38mm.
Expand cutouts to the left (towards the data/power connector). Expanding to the right will not leave enough space for mounting bracket (as discovered in the mechanical call.)
400W "air cooled" will be accepted as-is.
 
ACTION: Inspur will confirm the new dimensions and keep out for cooling internal to brick can be supported in brick designs.

ACTION: ASRock Rack will confirm the new dimensions and keep out for cooling internal to brick can be supported in brick designs.

ACTION: ASUS will confirm the new dimensions and keep out for cooling internal to brick can be supported in brick designs.
 
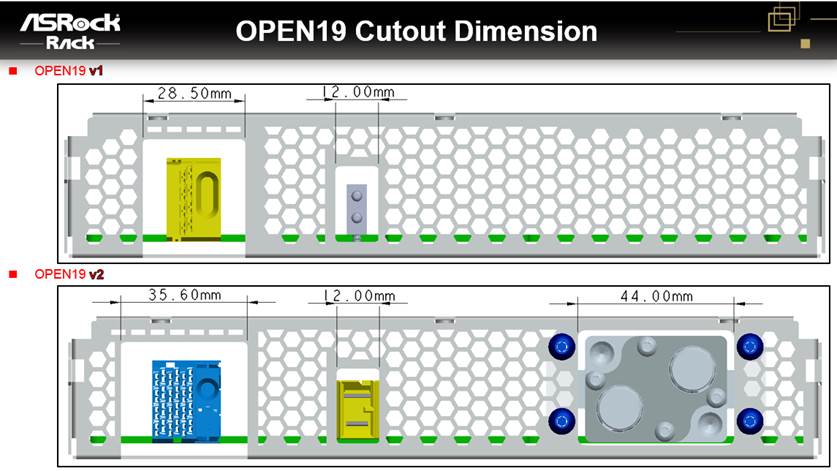
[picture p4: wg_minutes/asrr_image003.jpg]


== 2022 Jan 13

=== Attendees
* Julian Shui, Delta
* My Truong, Equinix
* Fred Rebarber, Vertiv
* Roy Grantham, Vertiv
* Peter Panfil, Vertiv
* John Leung, Inspur
* Trishan de Lanerolle, Linux Foundation
* Shahar Belkin, Zutacore

=== Discussion
- Keep out space for brick and cage. Need to finish keep outs in brick. Will try to close out in two weeks.
- ZutaCore will provide existing suggestions for keep out to Vertiv (Roy).

ACTION: Work with SE team on single-phase keep-out.

- Additional heat loads from accessories. Vertiv (Fred) is looking thermal models from server manufacturers. Fred will work with Six Sigma for data requirements.

   CTA: Provide/share any thermal models for server bricks that will land in racks. Fan curves and air flows are most interesting.

- Will we use ASHRE standards for liquid input? Need to discuss with the team.

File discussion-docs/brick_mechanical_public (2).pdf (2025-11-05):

# Open19 Brick Mechanical Specifications

### Linux Foundation Sustainable Scalable Infrastructure Alliance

# Table of Contents

# Open19 V2 Authors/Contributors

ASRock Rack: Weishi Sa

Cisco: Christopher Liljenstolpe

CoolIT: Brandon Peterson

Delta: Ralf Pieper

Equinix: Doug Asay, Suresh Pichai, My D. Truong

Inspur: John Leung, Kay Lu

Molex: Liz Hardin, Keegan McGraw, Chuck Crandley, Jeff Joniak

SE: Erin Mccann, Rob Bunger

Vertiv: Roy Grantham

ZutaCore: Shahar Belkin, Or Farjun

Open19 V2 Specification | 1

The Sustainable & Scalable Infrastructure Alliance (SSIA) is a community-based organization dedicated to creating, fostering and driving adoption of open standards that increase the efficiencies of the data center and digital infrastructure supply chains. We enable digital leaders from any sized organization to adopt and deploy advanced and highly efficient rack-level datacenter technologies to increase sustainability, power next-generation workloads and reduce cost and waste, regardless of deployment size or location.

SSIA members include data center operators, private and public cloud end users, supply chain manufacturers and technology component providers, as well as thousands of individual members active in the cloud, technology, data center and edge ecosystem.

Learn more about joining the Linux Foundation SSI Alliance at http://www.ssia.org/about-us/.

2 | FOR PUBLIC DISTRIBUTION

# Chapter 1. Change log

Author | Date | Version | Change Details
My Truong | November 2023 | 2.0 | Public Spec release

# Definitions

ASHRAE
American Society of Heating, Refrigerating and Air-Conditioning Engineers

ASHRAE W27
ASHRAE specification for water temperature range from 2 °C to 27 °C

OCP
Open Compute Project

SFP
SNIA SFF-8402 SFP+ 1X Pluggable Transceiver Solution

SNIA
Storage Networking Industry Association

QSFP
SNIA SFF-8679 QSFP+ 4X Pluggable Transceiver Solution

QSFP-DD
QSFP-DD MSA QSFP DOUBLE DENSITY 8X AND QSFP 4X PLUGGABLE TRANSCEIVERS

# Chapter 2. Open19 Bricks

Four brick designs are the basis of Open19 V2. They are:

- SHHW: Single-High Half-Width, "Brick"
- DHHW: Double-High Half-Width
- SHDW: Single-High Double-Width, 1RU server equivalent
- DHDW: Double-High Double-Width, 2RU server equivalent

# Chapter 3. Brick Mechanical Specification [SHHW]

# 3.1. SHHW Brick

The SHHW brick form-factor is a half-wide 1RU commonly used as the basis of 2U 4-node designs.

# 3.2. Brick Dimensions

The brick is designed with the overall dimensions shown.

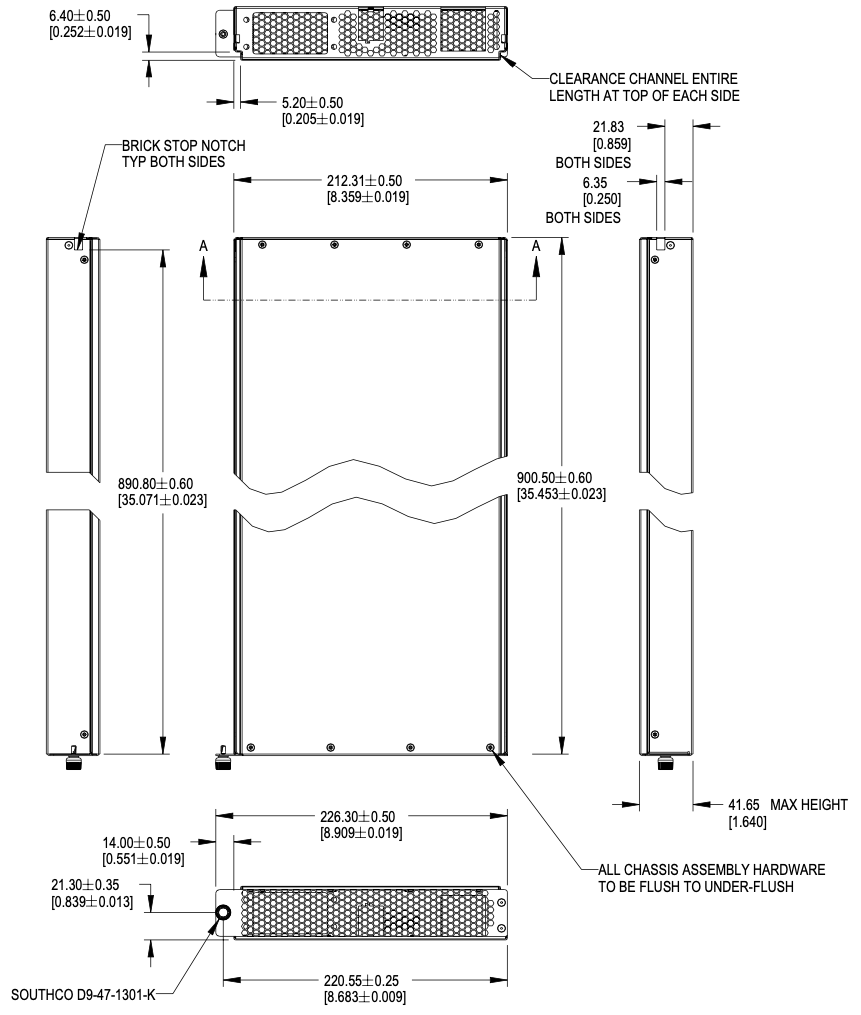
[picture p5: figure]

Figure 1. Brick dimensions

Please refer to the drawings, and 3D files for further details.

The V1 specification for bricks defined 901.7mm as the overall length of the brick, including the thickness of the front panel.

The dimension is modified to reference to the inside of the front panel to the rear of the brick. This dimension is 900.50mm +/-0.60 from the rear face of the front panel (mating surface to the cage) to the outside of the rear panel.

For half-width designs using the OCP DC-MHS M-DNO board specification, note the tolerance guidance in order to fit boards in a half-width chassis. This requires setting the nominal width at 209.55mm or smaller.

# 3.3. Mechanical features

### 3.3.1. Brick retention

The brick is secured into the cage with a single Southco D9-47-1302-K quarter-turn fastener, located on the left side of the faceplate. This is a change from V1. The change aligns the retention screw with high force areas of the optional liquid cooling interface.

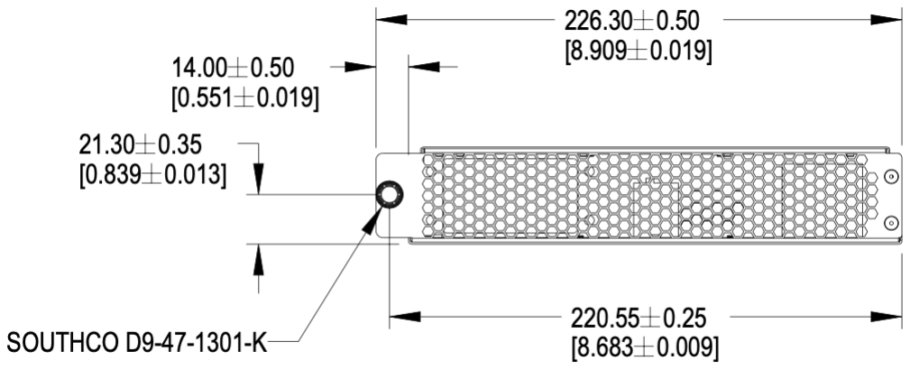
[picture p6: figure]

Figure 2. Brick retention

### 3.3.2. Brick mechanical guide

Clearance channels are required along the top edges of the brick, extending forward from the rear panel to the back of the faceplate.

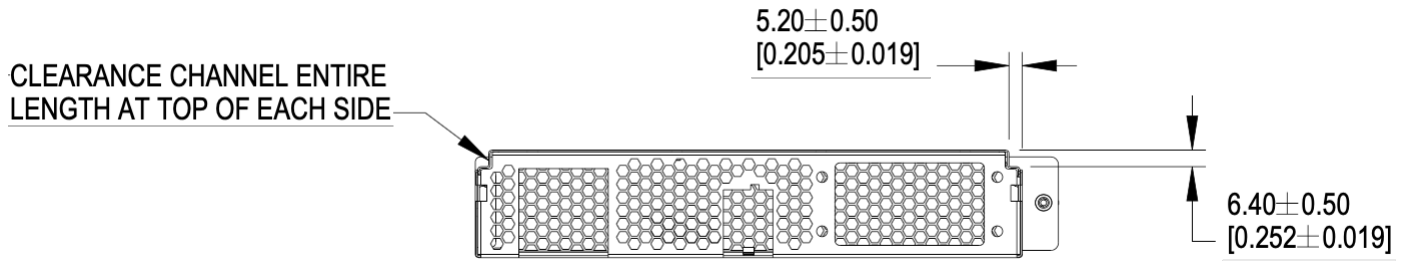
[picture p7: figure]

Figure 3. Mechanical guide at top edge of brick

Brick insertion and retention assistance for liquid cooling

For liquid cooling applications, two different mechanical assist for insertion and retention are available in the cage. Bricks can implement features to make use either/both features.

The features are:

- Brick retention standoff, available on both sides in the mechanical guide channel
- Slots, available on both sides of the cage wall

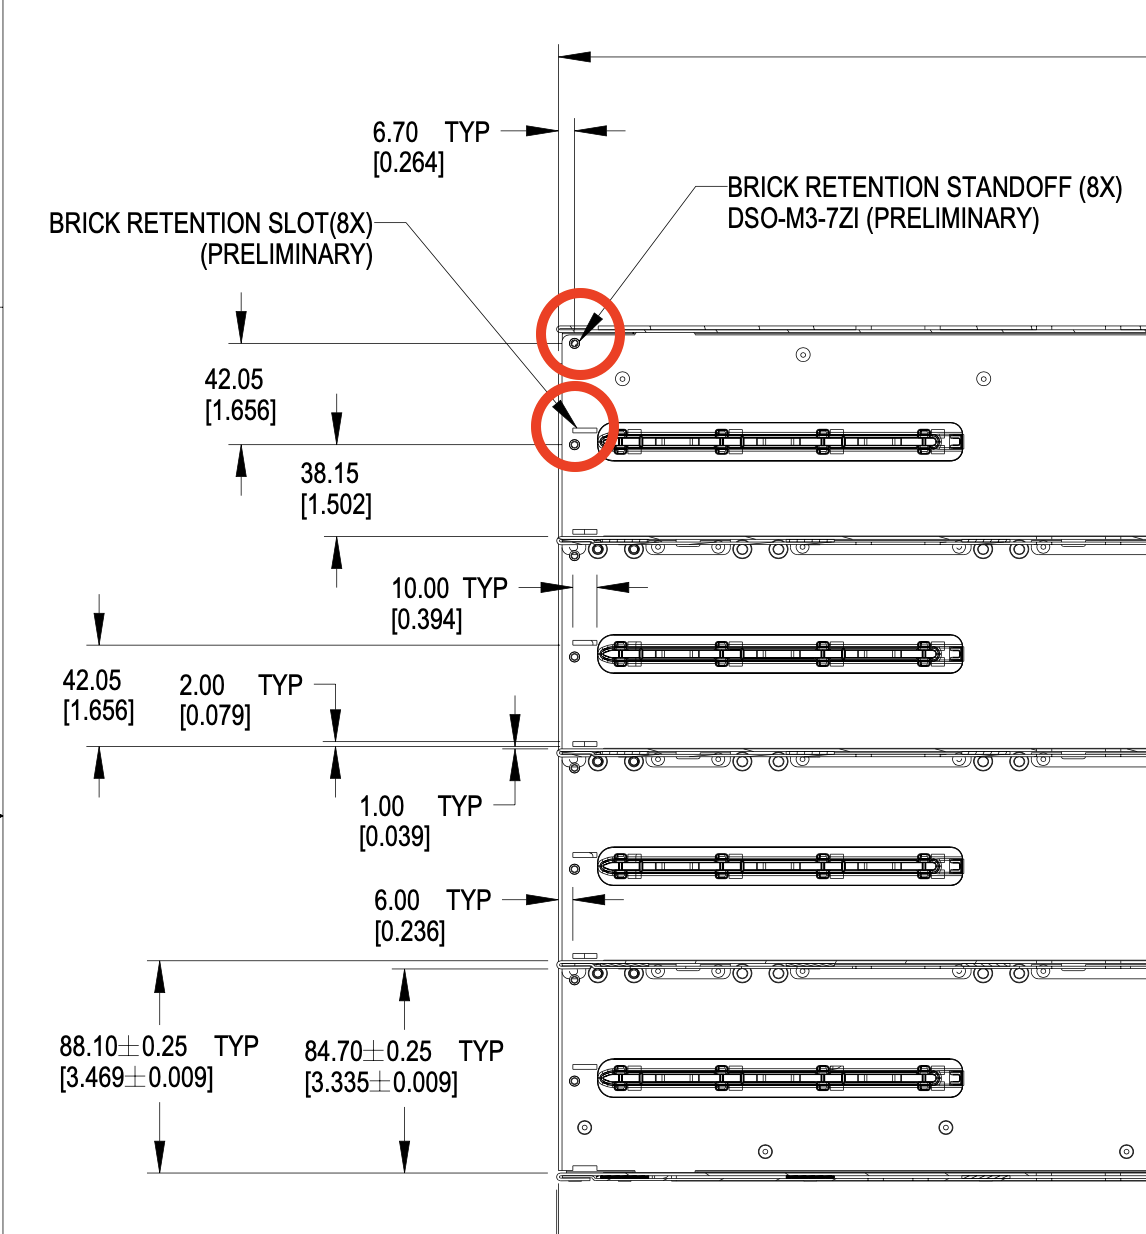
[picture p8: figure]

Figure 4. Brick mechanical assistance features in cage

Each feature shall support 100 lbf (445N) force or greater, using the recommended 1.3mm SGCC material.

### 3.3.3. Brick Mechanical Keying

Two keying notches are positioned in the left and right corners of the sheet metal enclosure as shown below. All dimensions below are critical.

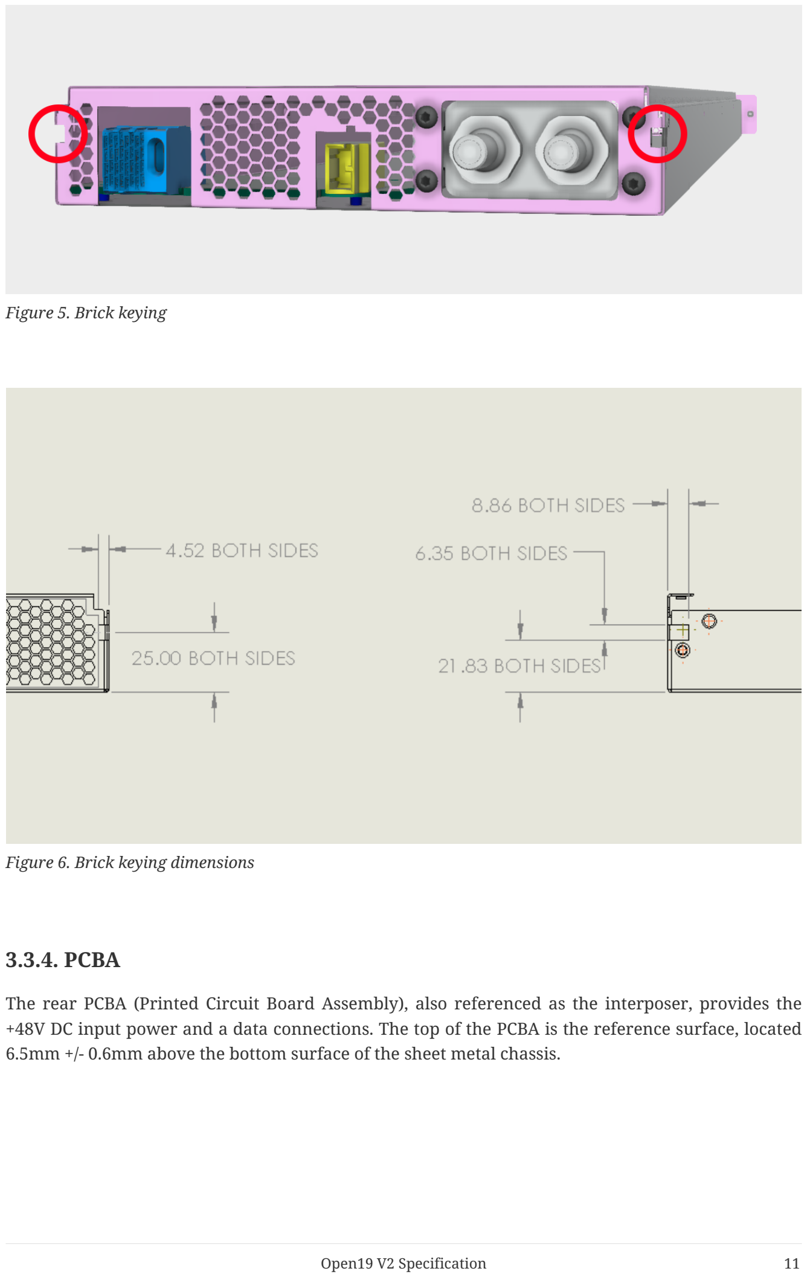
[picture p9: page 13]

Figure 5. Brick keying

Figure 6. Brick keying dimensions

### 3.3.4. PCBA

The rear PCBA (Printed Circuit Board Assembly), also referenced as the interposer, provides the +48V DC input power and a data connections. The top of the PCBA is the reference surface, located 6.5mm +/- 0.6mm above the bottom surface of the sheet metal chassis.

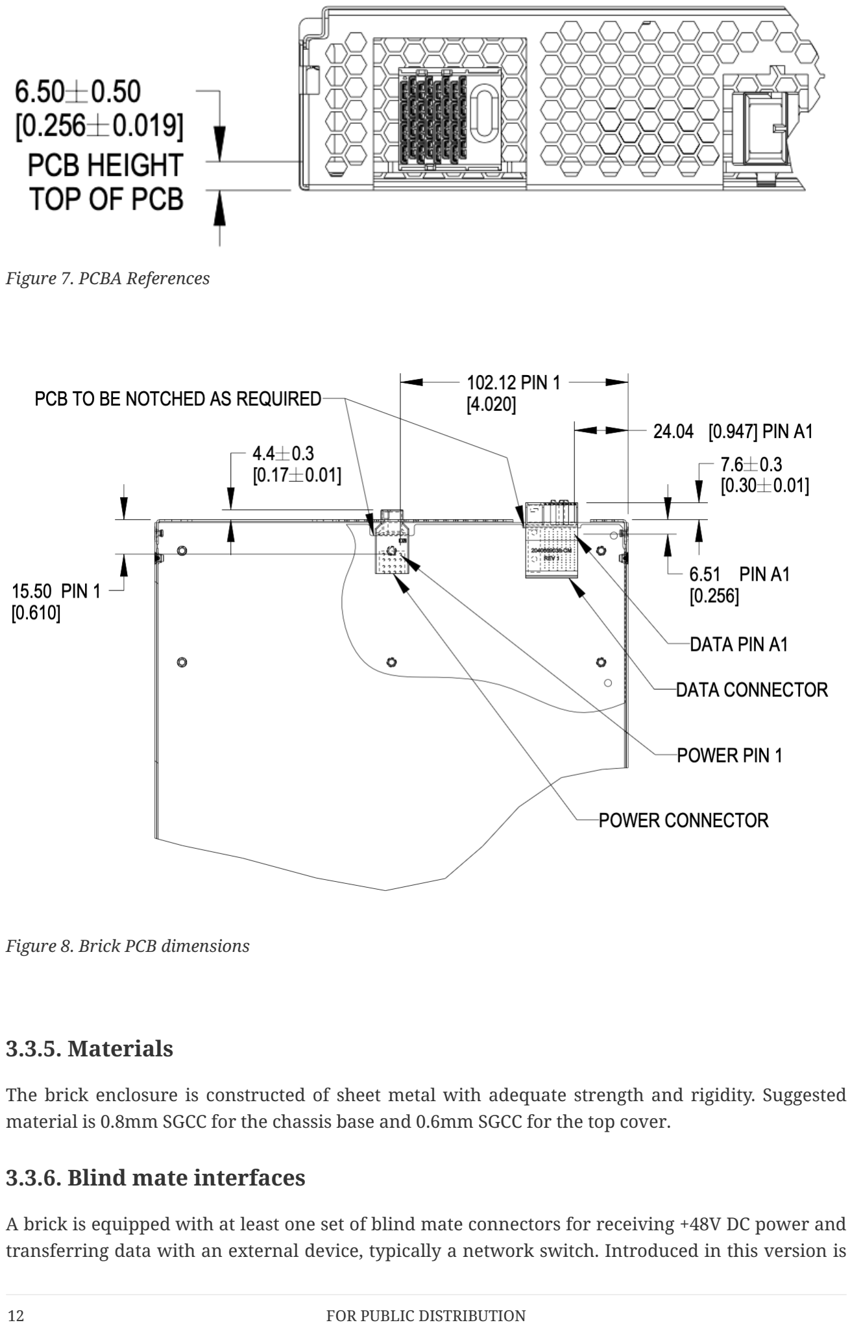
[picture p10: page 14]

Figure 7. PCBA References

Figure 8. Brick PCB dimensions

### 3.3.5. Materials

The brick enclosure is constructed of sheet metal with adequate strength and rigidity. Suggested material is 0.8mm SGCC for the chassis base and 0.6mm SGCC for the top cover.

### 3.3.6. Blind mate interfaces

A brick is equipped with at least one set of blind mate connectors for receiving +48V DC power and transferring data with an external device, typically a network switch. Introduced in this version is are blind mate connections to facilitate liquid cooling. The connections mate with cable and manifold projections from the rear wall of the cage.

- Power connector: Molex Ten60 PN: 220370-0001 (35A) 22037-0000 (70A), refer to Molex document PSD-220370-0000
- Data connector: Molex 4x8 Impel with guide receptacle PN: 204066-9038 (PCB thickness 2.2-4.1mm), 204066-9138 (PCB thickness 1.0-1.9mm), refer to Molex document PSD-204066-9001

The power connector has two ratings:

- Power: Not-To-Exceed (NTE) 70A at +48V DC
- Power: Not-To-Exceed (NTE) 35A at +48V DC

The ratings shall be coordinated with the power shelf. 35A bricks shall be enabled in 70A capable infrastructure. 70A bricks are keyed to prevent unsafe operation in 35A infrastructure.

### 3.3.7. Weight

The maximum weight of the brick, when equipped with all drives and/or accessories, is 30lbs (13.6kg). This is an increase of 5lbs from V1.

# 3.4. Connector Pinout

### 3.4.1. Brick power connector

The brick blind-mate power connector for receiving 48V DC (51V nominal) power from the power shelf. The connector mates with the power cable connector projected from the brick cage wall.

Two variations of the brick connector exist, with different Not-to-exceed (NTE) ratings:

- 35A Power Connector: Molex 2203700001 (NTE 35 AMPS) No Key
- 70A Power Connector: Molex 2203700000 (NTE 70 AMPS) Keyed

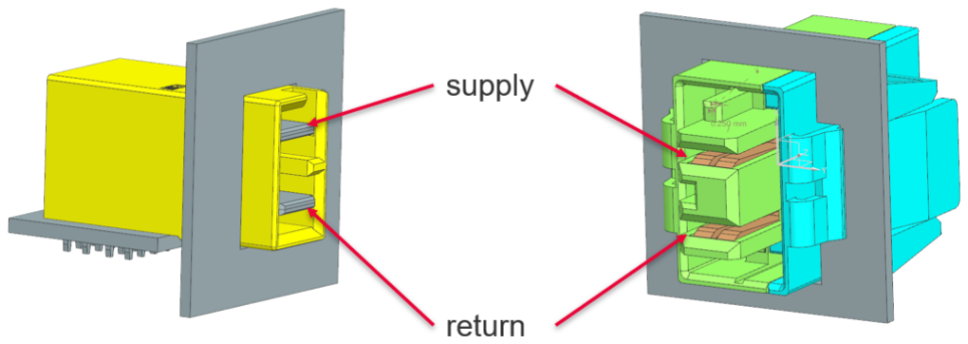
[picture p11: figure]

Figure 9. Power connector supply/return definition

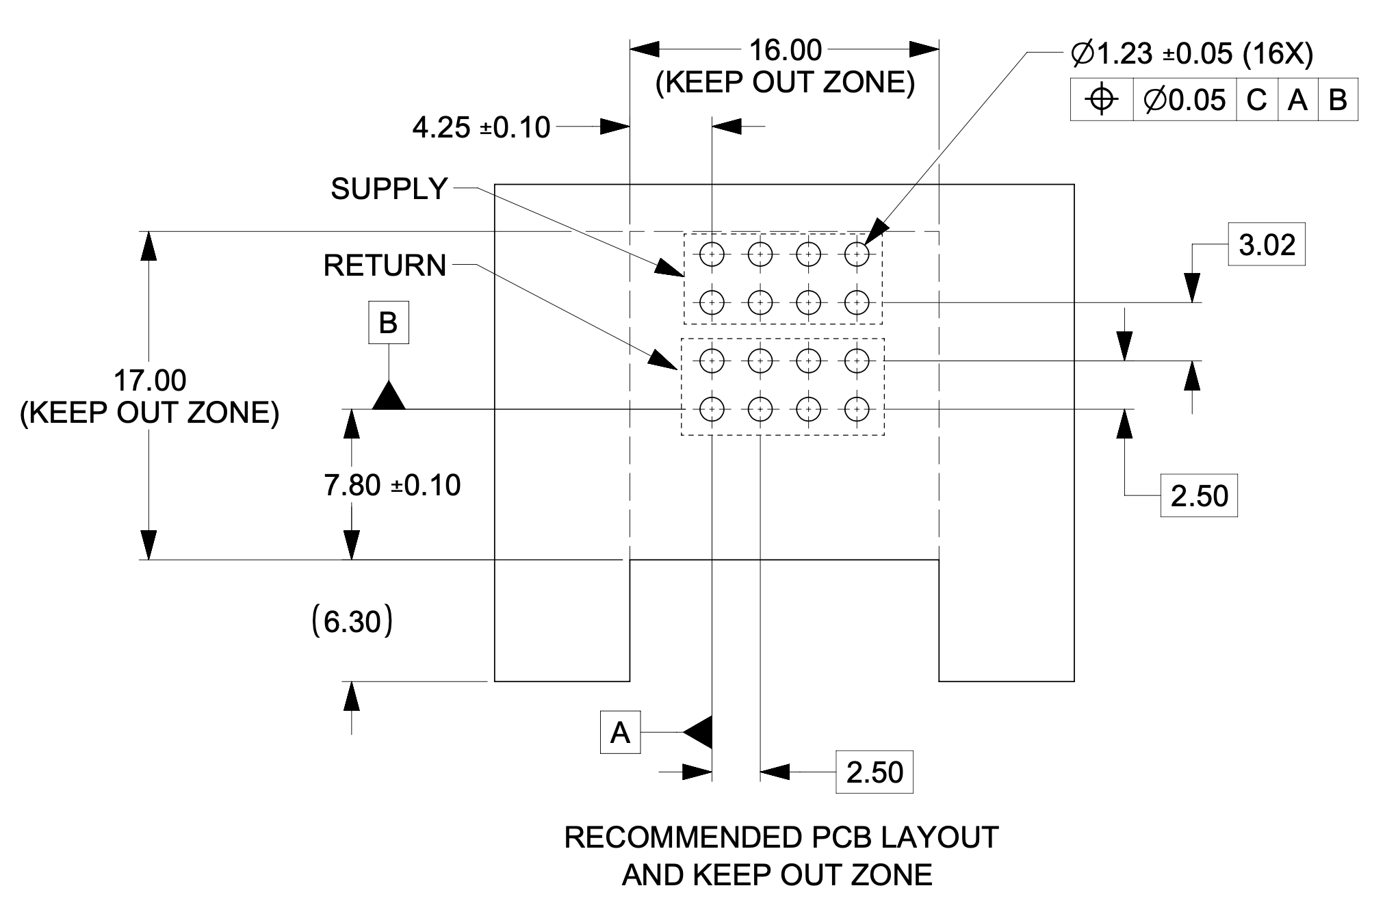
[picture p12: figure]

Figure 10. Power connector footprint definition

Connector drawings are available: Molex Brick power connector

### 3.4.2. Brick critical dimensions

The brick power connector has a critical dimension for the projection from the brick panel. Spacing between panels is 6.23mm. The power connector shall be proud of the panel 4.40mm.

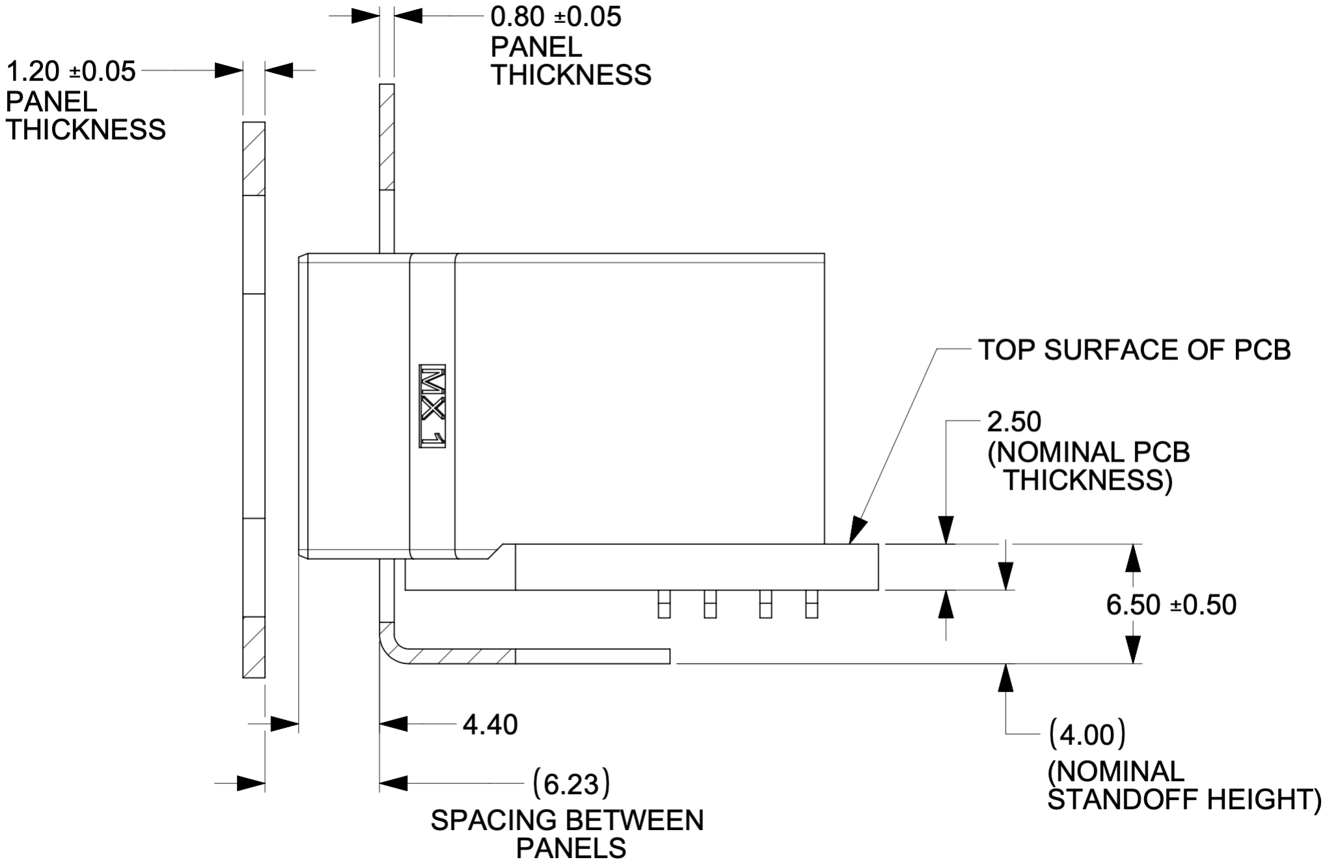
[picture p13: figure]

Figure 11. Power connector critical dimensions

### 3.4.3. Brick voltage

Open19 V2 power shares Open Compute ORV3 power characteristics. Open19 bricks shall safely operate in the DC range 48-52V and shall remain functional when exposed to 0-54V. The power rail shall not exceed 52.5V for more than 200mS. DC voltage shall never exceed 54V.

- Operating range: 48-52V
- NTE voltage: 54V
- Max voltage: ⇐52.5V for <200mS

### 3.4.4. Data Connector

The data connector is rated for 56G PAM4 with an air dielectric. Variations of cables deliver different lane counts, data rates, and physical interfaces. In the reference Ethernet implementation, the data connector pinout explicitly supports a dedicated 10/100/1000Base-T management port, four 25G NRZ/50G PAM4 lanes. Optionally, a single QSFP-DD or two QSFP interfaces are supported.

Figure 12. Impel Connector with guide feature

Figure 13. Impel Mated connector with cable backshell

The data connector pinout is defined in the [Appendix]

There is no attempt to support 50G (2x25G NRZ) nor 50G (1x50G NRZ).

### 3.4.5. Ethernet interface inter-operability

The inter-operability of bricks at deployment with Ethernet interfaces is critical. To support 25G NRZ, 50G PAM4, 100G (4x25G NRZ), 200G (4x50G PAM4), and 400G (8x50G PAM4), the following table:

Port Count | Data Rate | Implementation Interface and order
1 | 25G NRZ 50G PAM4 | SFP1
2 | | SFP1, SFP2
3 | | SFP1, SFP2, SFP3
4 | | SFP1, SPF2, SFP3, SPF4
5 | | SFP1, SPF2, SFP3, SPF4, QSFP1 LN 1
6 | | SFP1, SPF2, SFP3, SPF4, QSFP1 LN 1, QSFP2 LN 1
1 | 25G NRZ 50G PAM4 | SFP1
2 | | SFP1, SFP2
3 | | SFP1, SFP2, SFP3
4 | | SFP1, SPF2, SFP3, SPF4
5 | 100G (4x25G) 200G (4x50G PAM4) | SFP1, SPF2, SFP3, SPF4, QSFP1
6 | | SFP1, SPF2, SFP3, SPF4, QSFP1, QSFP2
1 | 25G NRZ 50G PAM4 | SFP1
2 | | SFP1, SFP2
3 | | SFP1, SFP2, SFP3
4 | | SFP1, SPF2, SFP3, SPF4
5 | 400G (8x50G PAM4) | QSFP-DD (QSFP1+QSFP2) 200G (4x50G PAM4)
QSFP (SFP1+SFP2+SFP3+ SFP4) | 2 | QSFP, QSFP1

# 3.5. Liquid cooling

### 3.5.1. Brick liquid cooling

Brick liquid cooling is divided into two broad categories, single-phase and two phase. They are mutually incompatible and the designs are mechanically incompatible by design. All bricks inside a single cage are expected to be the same liquid cooling technology.

Unified cutout

Open19 V2 liquid cooling implements a unified liquid cooling cutout. This allows for a consistent brick design to implement both liquid cooling solutions. Implementing the unified cutout is not required, provided all the requirements of a single solution are met.

Figure 14. Brick unified cooling cutout

### 3.5.2. Single phase

Single-phase Connector selection

Single-phase cooling solutions shall use the CPC BLQ4 (https://www.cpcworldwide.com/Products/Liquid-Cooling/Everis-BLQ4) family of interfaces.

Figure 15. BLQ4 body for manifold

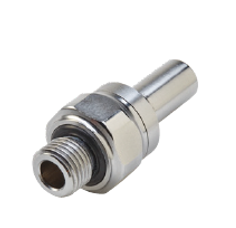
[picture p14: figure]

Figure 16. BLQ4 insert for bricks

BLQ4_SpecSheet.pdf

The BLQ4 connectors are blind mate. Both sides of the connector have G 3/8" threads which thread into manifold (body) and brick (insert), respectively.

Figure 17. BLQ4 pair

Single-phase connector mounting and polarization

Bricks shall have male blind-mate connectors (inserts), BLQ4D47006 or compatible part.

When viewed from the rear of the brick, in reference to the server: Liquid return shall be located to the left. Liquid supply shall be located in the to the right.

Figure 18. Brick side supply and return

Single-phase brick side connector locations

The supply connector should be 29.5mm from the outer side of the brick (opposite the thumbscrew) in the x-direction and 20.73mm from the bottom of face of the brick in the y-direction. THe two connectors should be lined up in the horizontal plane and spaced 28.5mm from each other.

Figure 19. Brick side liquid connector locations for single-phase

Single-phase offset depth

The mating surface of the brick side connector sits xx mm behind (outside) the outer edge of the back plane of the brick. Specifying this dimension ensures the server manufacturer and manifold/cage side implementor have a consistent location where the connectors must meet to ensure full mating and thereby full flow.

The reference mating surfaces of each connector are highlighted below along with a drawing showing the specified dimension.

Figure 20. Mating surface BLQ4 insert

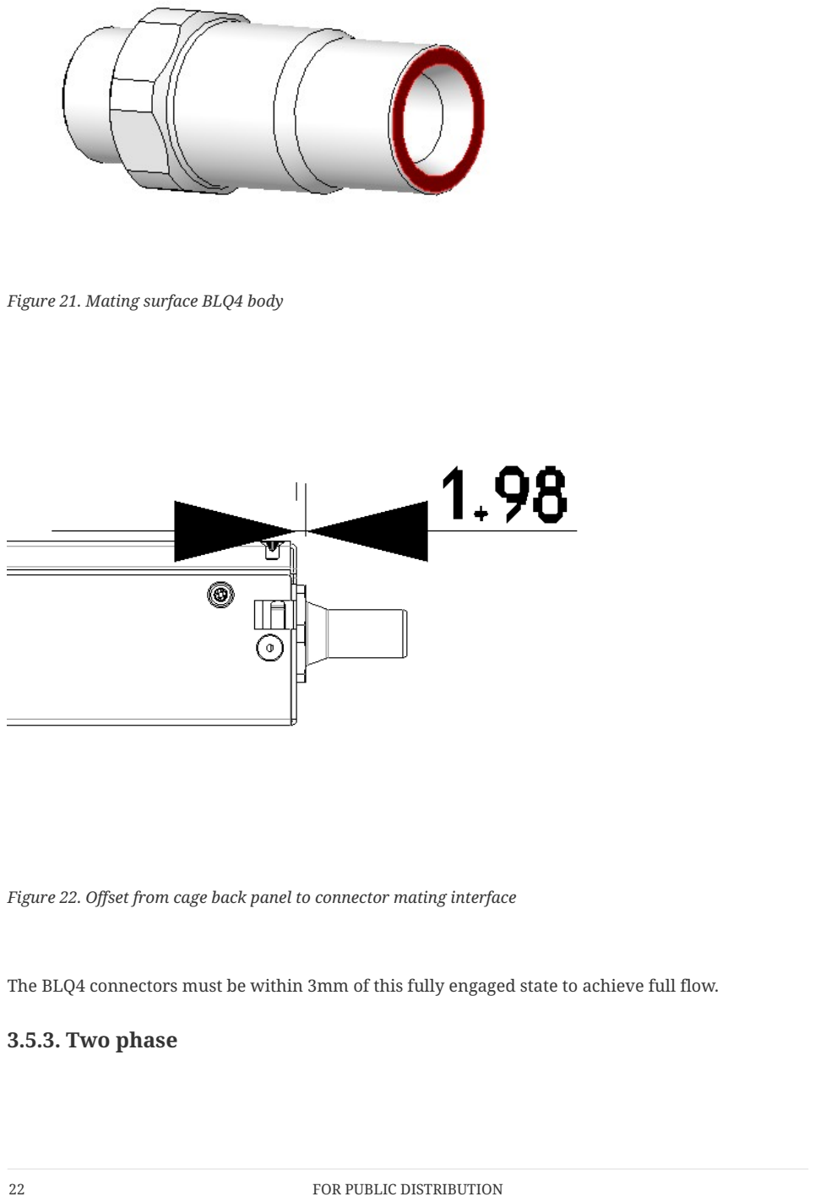
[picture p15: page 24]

Figure 21. Mating surface BLQ4 body

Figure 22. Offset from cage back panel to connector mating interface

The BLQ4 connectors must be within 3mm of this fully engaged state to achieve full flow.

### 3.5.3. Two phase

Two-phase connector selection

The two-phase cooling solution shall use the CPC BLQ family of interfaces.

On brick side

Figure 23. Liquid - CPC BLQ4 series insert P/N BLQ4D47004PROTO (chrome plated brass) or P/N 4649800PROTO (Aluminum)

Figure 24. Vapor - CPC BLQ6 series insert P/N 4650000PROTO (chrome plated brass)

On the Manifold side

Figure 25. Liquid - CPC BLQ4 series body P/N BLQ4D31004PROTO (chrome plated brass) or P/N 4649900PROTO (Aluminum)

Figure 26. Vapor - CPC BLQ6 series body P/N 4650200PROTO (chrome plated brass)

Two-phase connector mounting polarization

Cage manifolds shall have body (female) blind mate connectors. Bricks shall have insert (male) blind-mate connectors. When viewed from rear of the brick, vapor connection shall be located at the right position. Liquid connection shall be located at the left position.

Figure 27. Brick liquid supply and Vapor return

Two-phase brick side connector locations

Using the right-side panel of the brick as a reference, the Vapor return connector on the brick should be 31.85mm in the x direction and 20.73 upwards in the y direction.

Figure 28. Brick side connectors locations

Two-phase offset depth

The mating surface of the brick side connector sits xx mm behind (outside) the outer edge of the back plane of the brick. Specifying this dimension ensures the server manufacturer and manifold/cage side implementor have a consistent location where the connectors must meet to ensure full mating and thereby full flow.

The reference mating surfaces of each connector are highlighted below along with a drawing showing the specified dimension.

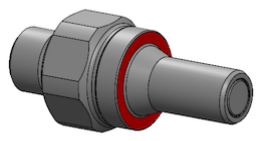
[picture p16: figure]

Figure 29. Mating surface BLQ4 insert

Figure 30. Mating surface BLQ4 body

Figure 31. Mating surface BLQ6 insert

Figure 32. Mating surface BLQ6 body

Figure 33. Offset from cage back panel to BLQ4 connector mating interface

Figure 34. Offset from cage back panel to BLQ6 connector mating interface

The BLQ4 & BLQ6 connectors must be within ±1.5mm of this engaged state to achieve full flow.

# 3.6. Design guidance

Design guidance is not a specification requirement. It is simple design guidance that can be implemented to simplify future needs, to meet certification requirements, or satisfy general fit & finish.

### 3.6.1. Brick faceplate guidance

The faceplate is notched above and below the fastener (See Figure 2, “Brick retention”). Note that the faceplate can accommodate any type of ports or drives as needed and is not required to be fully perforated.

Screws and/or rivets used to secure the top cover are flush to be under-flush. The vertical edges on the rear of the brick chassis base are coined to break sharp edges.

### 3.6.2. Back panel safety perforation

See below for typical dimensions of the airflow perforation. All dimensions below are critical.

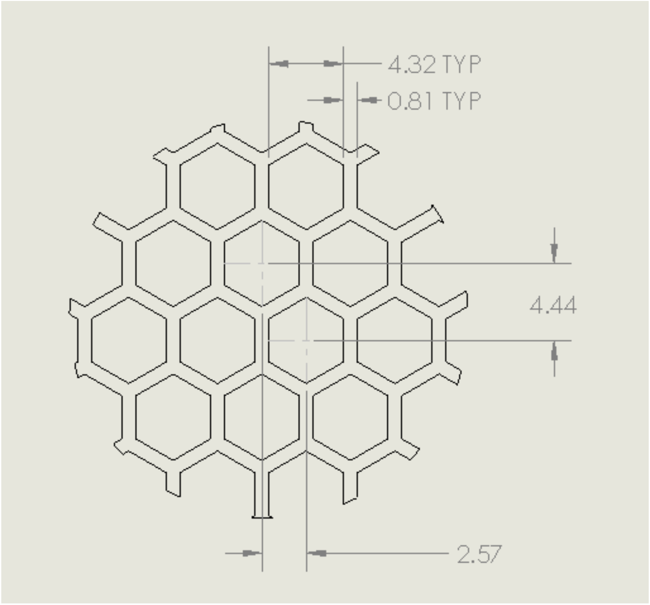
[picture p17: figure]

Figure 35. Brick panel perforation

Keep-out zones

Keep-out zones are defined in the brick surrounding the power connector and liquid cooling interfaces. The liquid cooling keep-out spaces "fly" above the PCB, allowing components to be populated below the connections.

Figure 36. Brick keep-out zone

Figure 37. Brick keep-out zone top view

# 3.7. Brick performance

### 3.7.1. Brick electrical startup behavior

In order to safely operate the power shelf, we define the following characteristics for brick startup behavior.

Figure 38. Server startup electrical characteristics

These values are per connector feed from a power shelf.

- Min start-up voltage: +44V DC
- Max input capacitance per brick feed: ⇐1000uF
- Max server current at start-up voltage: 70A
- Ramp time: Follow Intel CRPS spec: ramp time 10-70msec, slew rate 0.5V/msec

https://www.intel.com/content/dam/www/public/us/en/documents/guides/power-supply-design-guide-june.pdf (https://www.intel.com/content/dam/www/public/us/en/documents/guides/power-supply-design-guide-june.pdf)

# Chapter 4. Brick Mechanical Specification [DHHW]

# 4.1. DHHW Brick

The DHHW brick is commonly used as a 2U 2N server form-factor.

# 4.2. Brick Dimensions

The brick is designed with the overall dimensions shown.

Figure 39. Brick dimensions

Please refer to the drawings, and 3D files for further details.

The V1 specification for bricks defined 901.7mm as the overall length of the brick, including the thickness of the front panel.

The dimension is modified to reference to the inside of the front panel to the rear of the brick. This dimension is 900.50mm +/-0.60 from the rear face of the front panel (mating surface to the cage) to the outside of the rear panel.

For half-width designs using the OCP DC-MHS M-DNO board specification, note the tolerance guidance in order to fit boards in a half-width chassis. This requires setting the nominal width at 209.55mm or smaller.

# 4.3. Mechanical features

### 4.3.1. Brick retention

Brick are secured into the cage with Southco D9-47-1302-K quarter-turn fasteners.

Figure 40. Brick retention

### 4.3.2. Brick mechanical guide

Clearance channels are required along the top edges of the brick and the sidewalls, extending forward from the rear panel to the back of the faceplate.

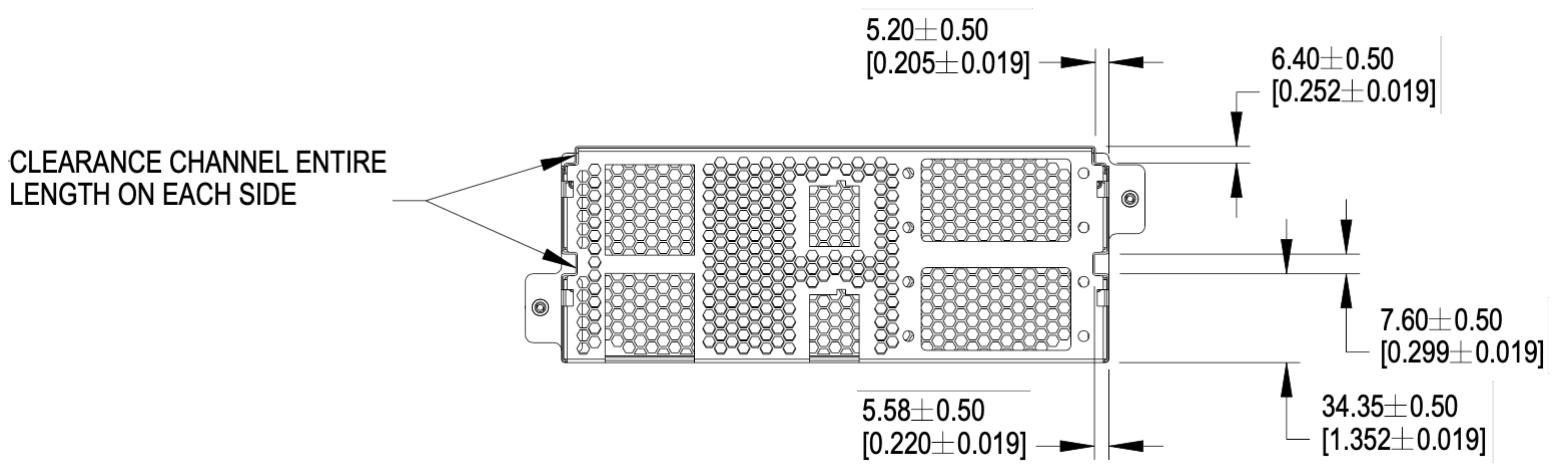
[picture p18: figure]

Figure 41. Mechanical guide at top edge and side walls of brick

Brick insertion and retention assistance for liquid cooling

For liquid cooling applications, two different mechanical assist for insertion and retention are available in the cage. Bricks can implement features to make use either/both features.

The features are:

- Brick retention standoff, available on both sides in the mechanical guide channel
- Slots, available on both sides of the cage wall

Figure 42. Brick mechanical assistance features in cage

Each feature shall support 100 lbf (445N) force or greater, using the recommended 1.3mm SGCC material.

### 4.3.3. Brick Mechanical Keying

Two keying notches are positioned in the left and right corners of the sheet metal enclosure as shown below. All dimensions below are critical.

Figure 43. Brick keying

Figure 44. Brick keying dimensions

### 4.3.4. PCBA

The rear PCBA (Printed Circuit Board Assembly), also referenced as the interposer, provides the +48V DC input power and a data connections. The top of the PCBA is the reference surface, located 6.5mm +/- 0.6mm above the bottom surface of the sheet metal chassis.

A second PCBA may be installed at 48.55mm +/- 0.5mm above the bottom surface of the chassis.

Figure 45. PCBA References

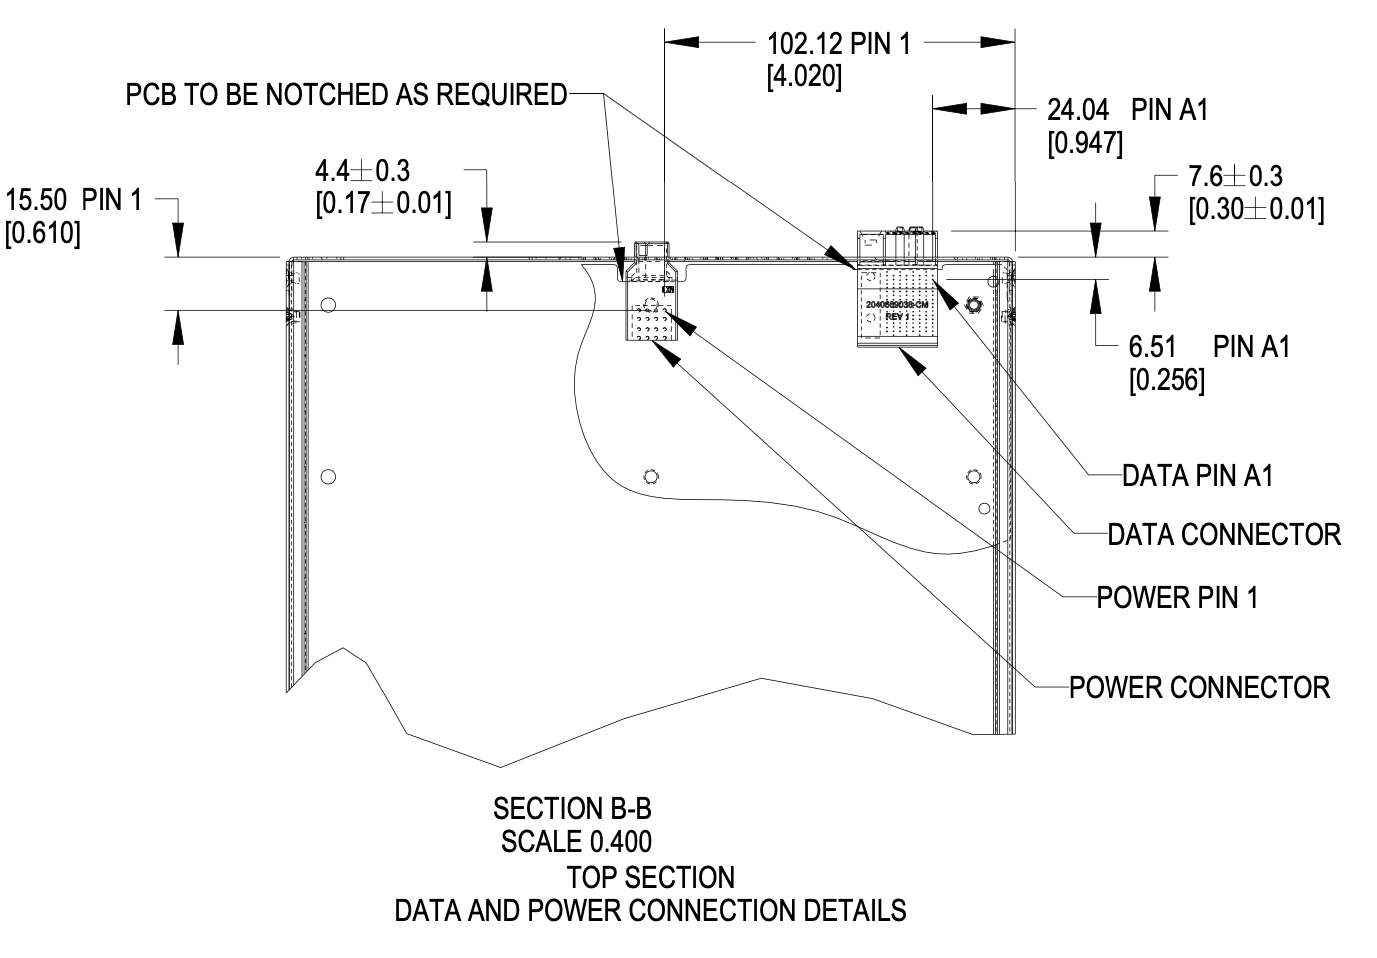
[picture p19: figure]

Figure 46. Brick PCB dimensions

One set of connectors are shown in the image. Two sets are available in a brick.

### 4.3.5. Materials

The brick enclosure is constructed of sheet metal with adequate strength and rigidity. Suggested material is 0.8mm SGCC for the chassis base and 0.6mm SGCC for the top cover.

### 4.3.6. Blind mate interfaces

A brick is equipped with at least one set of blind mate connectors for receiving +48V DC power and transferring data with an external device, typically a network switch. Introduced in this version is are blind mate connections to facilitate liquid cooling. The connections mate with cable and manifold projections from the rear wall of the cage.

- Power connector: Molex Ten60 PN: 220370-0001 (35A) 22037-0000 (70A), refer to Molex document PSD-220370-0000
- Data connector: Molex 4x8 Impel with guide receptacle PN: 204066-9038 (PCB thickness 2.2-4.1mm), 204066-9138 (PCB thickness 1.0-1.9mm), refer to Molex document PSD-204066-9001

The power connector has two ratings:

- Power: Not-To-Exceed (NTE) 70A at +48V DC
- Power: Not-To-Exceed (NTE) 35A at +48V DC

The ratings shall be coordinated with the power shelf. 35A bricks shall be enabled in 70A capable infrastructure. 70A bricks are keyed to prevent unsafe operation in 35A infrastructure.

The brick may populate a second set of connectors, as required.

# 4.4. Connector Pinout

### 4.4.1. Brick power connector

The brick blind-mate power connector for receiving 48V DC (51V nominal) power from the power shelf. The connector mates with the power cable connector projected from the brick cage wall.

Two variations of the brick connector exist, with different Not-to-exceed (NTE) ratings:

- 35A Power Connector: Molex 2203700001 (NTE 35 AMPS) No Key
- 70A Power Connector: Molex 2203700000 (NTE 70 AMPS) Keyed

Figure 47. Power connector supply/return definition

Figure 48. Power connector footprint definition

Connector drawings are available: Molex Brick power connector

### 4.4.2. Brick critical dimensions

The brick power connector has a critical dimension for the projection from the brick panel. Spacing between panels is 6.23mm. The power connector shall be proud of the panel 4.40mm.

Figure 49. Power connector critical dimensions

### 4.4.3. Brick voltage

Open19 V2 power shares Open Compute ORV3 power characteristics. Open19 bricks shall safely operate in the DC range 48-52V and shall remain functional when exposed to 0-54V. The power rail shall not exceed 52.5V for more than 200mS. DC voltage shall never exceed 54V.

- Operating range: 48-52V
- NTE voltage: 54V
- Max voltage: ⇐52.5V for <200mS

### 4.4.4. Data Connector

The data connector is rated for 56G PAM4 with an air dielectric. Variations of cables deliver different lane counts, data rates, and physical interfaces. In the reference Ethernet implementation, the data connector pinout explicitly supports a dedicated 10/100/1000Base-T management port, four 25G NRZ/50G PAM4 lanes. Optionally, a single QSFP-DD or two QSFP interfaces are supported.

Figure 50. Impel Connector with guide feature

Figure 51. Impel Mated connector with cable backshell

The data connector pinout is defined in the [Appendix]

There is no attempt to support 50G (2x25G NRZ) nor 50G (1x50G NRZ).

### 4.4.5. Ethernet interface inter-operability

The inter-operability of bricks at deployment with Ethernet interfaces is critical. To support 25G NRZ, 50G PAM4, 100G (4x25G NRZ), 200G (4x50G PAM4), and 400G (8x50G PAM4), the following table:

Port Count | Data Rate | Implementation Interface and order
1 | 25G NRZ 50G PAM4 | SFP1
2 | | SFP1, SFP2
3 | | SFP1, SFP2, SFP3
4 | | SFP1, SPF2, SFP3, SPF4
5 | | SFP1, SPF2, SFP3, SPF4, QSFP1 LN 1
6 | | SFP1, SPF2, SFP3, SPF4, QSFP1 LN 1, QSFP2 LN 1
1 | 25G NRZ 50G PAM4 | SFP1
2 | | SFP1, SFP2
3 | | SFP1, SFP2, SFP3
4 | | SFP1, SPF2, SFP3, SPF4
5 | 100G (4x25G) 200G (4x50G PAM4) | SFP1, SPF2, SFP3, SPF4, QSFP1
6 | | SFP1, SPF2, SFP3, SPF4, QSFP1, QSFP2
1 | 25G NRZ 50G PAM4 | SFP1
2 | | SFP1, SFP2
3 | | SFP1, SFP2, SFP3
4 | | SFP1, SPF2, SFP3, SPF4
5 | 400G (8x50G PAM4) | QSFP-DD (QSFP1+QSFP2) 200G (4x50G PAM4)
QSFP (SFP1+SFP2+SFP3+ SFP4) | 2 | QSFP, QSFP1

# 4.5. Liquid cooling

### 4.5.1. Brick liquid cooling

Brick liquid cooling is divided into two broad categories, single-phase and two phase. They are mutually incompatible and the designs are mechanically incompatible by design. All bricks inside a single cage are expected to be the same liquid cooling technology.

Unified cutout

Open19 V2 liquid cooling implements a unified liquid cooling cutout. This allows for a consistent brick design to implement both liquid cooling solutions. Implementing the unified cutout is not required, provided all the requirements of a single solution are met.

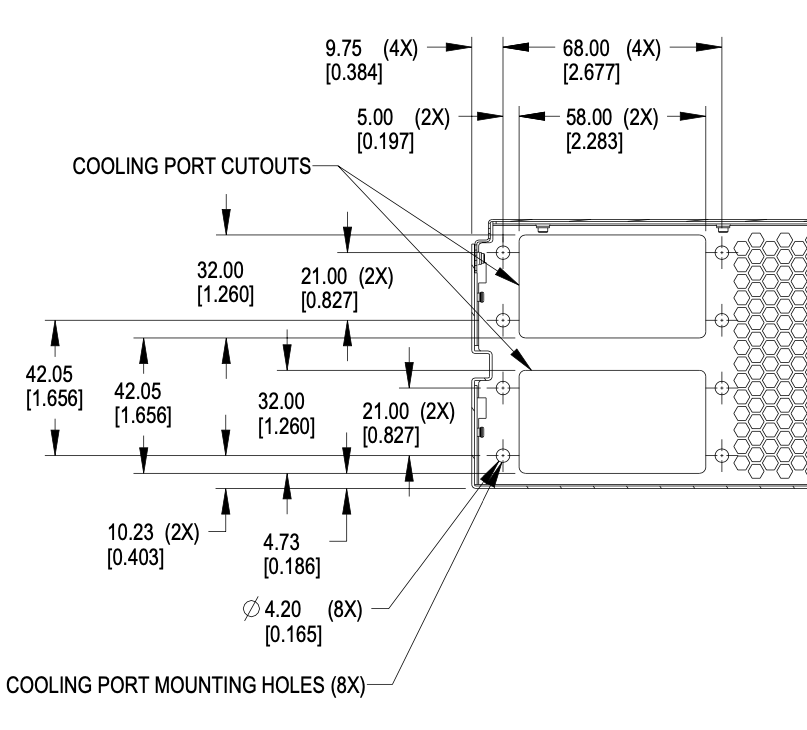
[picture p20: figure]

Figure 52. Brick unified cooling cutout

### 4.5.2. Single phase

Single-phase Connector selection

Single-phase cooling solutions shall use the CPC BLQ4 (https://www.cpcworldwide.com/Products/Liquid-Cooling/Everis-BLQ4) family of interfaces.

Figure 53. BLQ4 body for manifold

Figure 54. BLQ4 insert for bricks

BLQ4_SpecSheet.pdf

The BLQ4 connectors are blind mate. Both sides of the connector have G 3/8" threads which thread into manifold (body) and brick (insert), respectively.

Figure 55. BLQ4 pair

Single-phase connector mounting and polarization

Bricks shall have male blind-mate connectors (inserts), BLQ4D47006 or compatible part.

When viewed from the rear of the brick, in reference to the server: Liquid return shall be located to the left. Liquid supply shall be located in the to the right.

Figure 56. Brick side supply and return

Single-phase brick side connector locations

The supply connector should be 29.5mm from the outer side of the brick (opposite the thumbscrew) in the x-direction and 20.73mm from the bottom of face of the brick in the y-direction. THe two connectors should be lined up in the horizontal plane and spaced 28.5mm from each other.

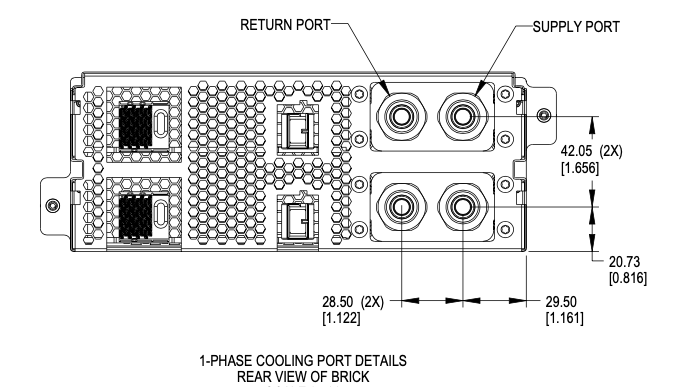
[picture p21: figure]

Figure 57. Brick side liquid connector locations for single-phase

Single-phase offset depth

The mating surface of the brick side connector sits xx mm behind (outside) the outer edge of the back plane of the brick. Specifying this dimension ensures the server manufacturer and manifold/cage side implementor have a consistent location where the connectors must meet to ensure full mating and thereby full flow.

The reference mating surfaces of each connector are highlighted below along with a drawing showing the specified dimension.

Figure 58. Mating surface BLQ4 insert

Figure 59. Mating surface BLQ4 body

Figure 60. Offset from cage back panel to connector mating interface

The BLQ4 connectors must be within 3mm of this fully engaged state to achieve full flow.

### 4.5.3. Two phase

Two-phase connector selection

The two-phase cooling solution shall use the CPC BLQ family of interfaces.

On brick side

Figure 61. Liquid - CPC BLQ4 series insert P/N BLQ4D47004PROTO (chrome plated brass) or P/N 4649800PROTO (Aluminum)

Figure 62. Vapor - CPC BLQ6 series insert P/N 4650000PROTO (chrome plated brass)

On the Manifold side

Figure 63. Liquid - CPC BLQ4 series body P/N BLQ4D31004PROTO (chrome plated brass) or P/N 4649900PROTO (Aluminum)

Figure 64. Vapor - CPC BLQ6 series body P/N 4650200PROTO (chrome plated brass)

Two-phase connector mounting polarization

Cage manifolds shall have body (female) blind mate connectors. Bricks shall have insert (male) blind-mate connectors. When viewed from rear of the brick, vapor connection shall be located at the right position. Liquid connection shall be located at the left position.

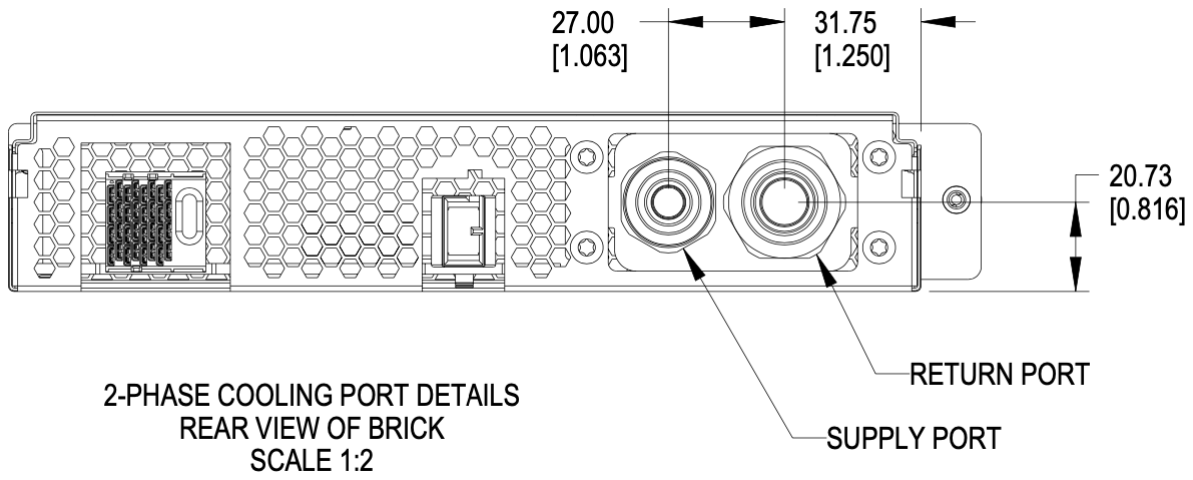
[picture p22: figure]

Figure 65. Brick liquid supply and Vapor return

Two-phase brick side connector locations

Using the right-side panel of the brick as a reference, the Vapor return connector on the brick should be 31.85mm in the x direction and 20.73 upwards in the y direction.

Figure 66. Brick side connectors locations

Two-phase offset depth

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

Figure 67. Mating surface BLQ4 insert

Figure 68. Mating surface BLQ4 body

Figure 69. Mating surface BLQ6 insert

Figure 70. Mating surface BLQ6 body

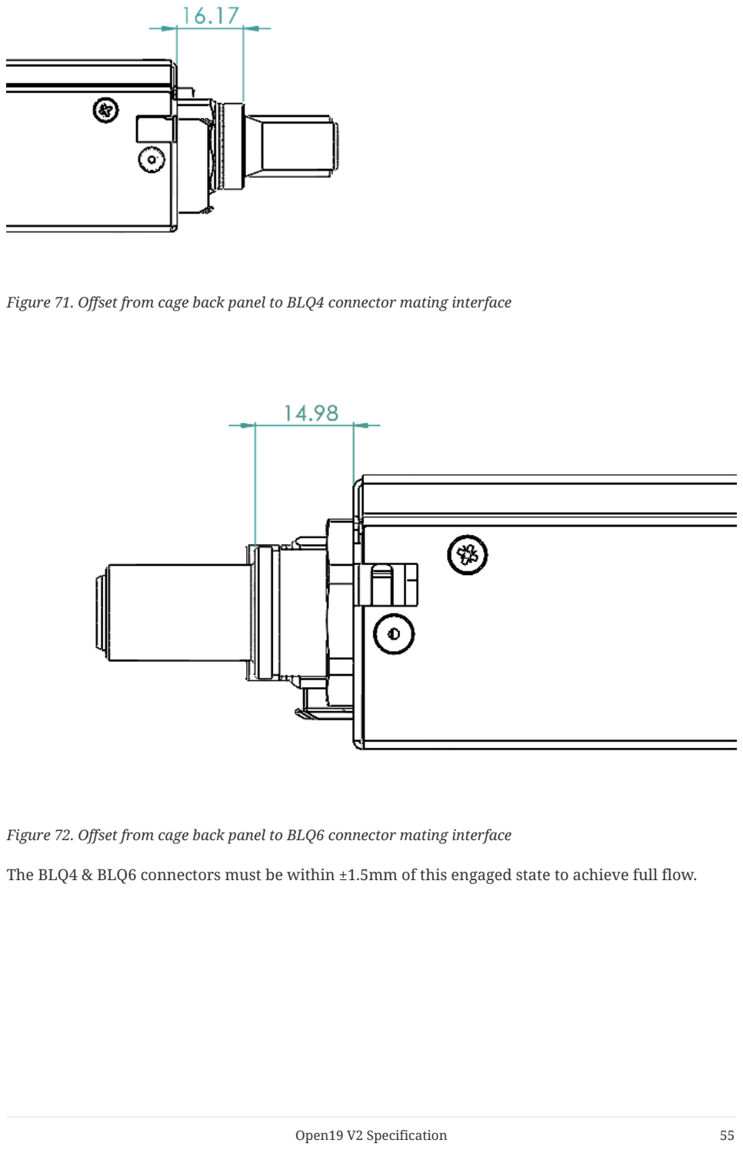
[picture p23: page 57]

Figure 71. Offset from cage back panel to BLQ4 connector mating interface

Figure 72. Offset from cage back panel to BLQ6 connector mating interface

The BLQ4 & BLQ6 connectors must be within ±1.5mm of this engaged state to achieve full flow.

### 4.5.4. Weight

The maximum weight of the brick, when equipped with all drives and/or accessories, is 60lbs (13.6kg). This is an increase of 10lbs from V1.

### 4.5.5. Design guidance

Design guidance is not a specification requirement. It is simple design guidance that can be implemented to simplify future needs, to meet certification requirements, or satisfy general fit & finish.

### 4.5.6. Brick faceplate guidance

The faceplate is notched above and below the fastener (See Figure 40, “Brick retention”). Note that the faceplate can accommodate any type of ports or drives as needed and is not required to be fully perforated.

Screws and/or rivets used to secure the top cover are flush to be under-flush. The vertical edges on the rear of the brick chassis base are coined to break sharp edges.

### 4.5.7. Back panel safety perforation

See below for typical dimensions of the airflow perforation. All dimensions below are critical.

Figure 73. Brick panel perforation

Keep-out zones

Keep-out zones are defined in the brick surrounding the power connector and liquid cooling interfaces. The liquid cooling keep-out spaces "fly" above the PCB, allowing components to be populated below the connections.

Figure 74. Brick keep-out zone

Figure 75. Brick keep-out zone top view

# 4.6. Brick performance

### 4.6.1. Brick electrical startup behavior

In order to safely operate the power shelf, we define the following characteristics for brick startup behavior.

Figure 76. Server startup electrical characteristics

These values are per connector feed from a power shelf.

Two power connectors are available for use.

- Min start-up voltage: +44V DC
- Max input capacitance per brick feed: ⇐1000uF
- Max server current at start-up voltage: 70A
- Ramp time: Follow Intel CRPS spec: ramp time 10-70msec, slew rate 0.5V/msec

https://www.intel.com/content/dam/www/public/us/en/documents/guides/power-supply-design-guide-june.pdf (https://www.intel.com/content/dam/www/public/us/en/documents/guides/power-supply-design-guide-june.pdf)

# Chapter 5. Brick Mechanical Specification [SHDW]

# 5.1. SHDW Brick

The SHDW brick is commonly used as a 1RU server form-factor.

# 5.2. Brick Dimensions

The brick is designed with the overall dimensions shown.

Figure 77. Brick dimensions

Please refer to the drawings, and 3D files for further details.

The V1 specification for bricks defined 901.7mm as the overall length of the brick, including the thickness of the front panel.

The dimension is modified to reference to the inside of the front panel to the rear of the brick. This dimension is 900.50mm +/-0.60 from the rear face of the front panel (mating surface to the cage) to the outside of the rear panel.

# 5.3. Mechanical features

### 5.3.1. Brick retention

The brick is secured into the cage with two Southco D9-47-1302-K quarter-turn fastener, located on the left and right side of the faceplate.

Figure 78. Brick retention

### 5.3.2. Brick mechanical guide

Clearance channels are required along the top edges of the brick, extending forward from the rear panel to the back of the faceplate.

Figure 79. Mechanical guide at top edge of brick

Brick insertion and retention assistance for liquid cooling

For liquid cooling applications, two different mechanical assist for insertion and retention are available in the cage. Bricks can implement features to make use either/both features.

The features are:

- Brick retention standoff, available on both sides in the mechanical guide channel
- Slots, available on both sides of the cage wall

Figure 80. Brick mechanical assistance features in cage

Each feature shall support 100 lbf (445N) force or greater, using the recommended 1.3mm SGCC material.

### 5.3.3. Brick Mechanical Keying

Two keying notches are positioned in the left and right corners of the sheet metal enclosure as shown below. All dimensions below are critical.

Figure 81. Brick keying

Figure 82. Brick keying dimensions

### 5.3.4. PCBA

The rear PCBA (Printed Circuit Board Assembly), also referenced as the interposer, provides the +48V DC input power and a data connections. The top of the PCBA is the reference surface, located 6.5mm +/- 0.6mm above the bottom surface of the sheet metal chassis.

Figure 83. PCBA References

Figure 84. Brick PCB dimensions

### 5.3.5. Materials

The brick enclosure is constructed of sheet metal with adequate strength and rigidity. Suggested material is 0.8mm SGCC for the chassis base and 0.6mm SGCC for the top cover.

### 5.3.6. Blind mate interfaces

A brick is equipped with at least one set of blind mate connectors for receiving +48V DC power and transferring data with an external device, typically a network switch. Introduced in this version is are blind mate connections to facilitate liquid cooling. The connections mate with cable and manifold projections from the rear wall of the cage.

- Power connector: Molex Ten60 PN: 220370-0001 (35A) 22037-0000 (70A), refer to Molex document PSD-220370-0000
- Data connector: Molex 4x8 Impel with guide receptacle PN: 204066-9038 (PCB thickness 2.2-4.1mm), 204066-9138 (PCB thickness 1.0-1.9mm), refer to Molex document PSD-204066-9001

The power connector has two ratings:

- Power: Not-To-Exceed (NTE) 70A at +48V DC
- Power: Not-To-Exceed (NTE) 35A at +48V DC

The ratings shall be coordinated with the power shelf. 35A bricks shall be enabled in 70A capable infrastructure. 70A bricks are keyed to prevent unsafe operation in 35A infrastructure.

The brick may populate a second set of connectors, as required.

### 5.3.7. Weight

The maximum weight of the brick, when equipped with all drives and/or accessories, is 60lbs (13.6kg). This is an increase of 10lbs from V1.

# 5.4. Connector Pinout

### 5.4.1. Brick power connector

The brick blind-mate power connector for receiving 48V DC (51V nominal) power from the power shelf. The connector mates with the power cable connector projected from the brick cage wall.

Two variations of the brick connector exist, with different Not-to-exceed (NTE) ratings:

- 35A Power Connector: Molex 2203700001 (NTE 35 AMPS) No Key
- 70A Power Connector: Molex 2203700000 (NTE 70 AMPS) Keyed

Figure 85. Power connector supply/return definition

Figure 86. Power connector footprint definition

Connector drawings are available: Molex Brick power connector

### 5.4.2. Brick critical dimensions

The brick power connector has a critical dimension for the projection from the brick panel. Spacing between panels is 6.23mm. The power connector shall be proud of the panel 4.40mm.

Figure 87. Power connector critical dimensions

### 5.4.3. Brick voltage

Open19 V2 power shares Open Compute ORV3 power characteristics. Open19 bricks shall safely operate in the DC range 48-52V and shall remain functional when exposed to 0-54V. The power rail shall not exceed 52.5V for more than 200mS. DC voltage shall never exceed 54V.

- Operating range: 48-52V
- NTE voltage: 54V
- Max voltage: ⇐52.5V for <200mS

### 5.4.4. Data Connector

The data connector is rated for 56G PAM4 with an air dielectric. Variations of cables deliver different lane counts, data rates, and physical interfaces. In the reference Ethernet implementation, the data connector pinout explicitly supports a dedicated 10/100/1000Base-T management port, four 25G NRZ/50G PAM4 lanes. Optionally, a single QSFP-DD or two QSFP interfaces are supported.

Figure 88. Impel Connector with guide feature

Figure 89. Impel Mated connector with cable backshell

The data connector pinout is defined in the [Appendix]

There is no attempt to support 50G (2x25G NRZ) nor 50G (1x50G NRZ).

### 5.4.5. Ethernet interface inter-operability

The inter-operability of bricks at deployment with Ethernet interfaces is critical. To support 25G NRZ, 50G PAM4, 100G (4x25G NRZ), 200G (4x50G PAM4), and 400G (8x50G PAM4), the following table:

Port Count | Data Rate | Implementation Interface and order
1 | 25G NRZ 50G PAM4 | SFP1
2 | | SFP1, SFP2
3 | | SFP1, SFP2, SFP3
4 | | SFP1, SPF2, SFP3, SPF4
5 | | SFP1, SPF2, SFP3, SPF4, QSFP1 LN 1
6 | | SFP1, SPF2, SFP3, SPF4, QSFP1 LN 1, QSFP2 LN 1
1 | 25G NRZ 50G PAM4 | SFP1
2 | | SFP1, SFP2
3 | | SFP1, SFP2, SFP3
4 | | SFP1, SPF2, SFP3, SPF4
5 | 100G (4x25G) 200G (4x50G PAM4) | SFP1, SPF2, SFP3, SPF4, QSFP1
6 | | SFP1, SPF2, SFP3, SPF4, QSFP1, QSFP2
1 | 25G NRZ 50G PAM4 | SFP1
2 | | SFP1, SFP2
3 | | SFP1, SFP2, SFP3
4 | | SFP1, SPF2, SFP3, SPF4
5 | 400G (8x50G PAM4) | QSFP-DD (QSFP1+QSFP2) 200G (4x50G PAM4)
QSFP (SFP1+SFP2+SFP3+ SFP4) | 2 | QSFP, QSFP1

# 5.5. Liquid cooling

### 5.5.1. Brick liquid cooling

Brick liquid cooling is divided into two broad categories, single-phase and two phase. They are mutually incompatible and the designs are mechanically incompatible by design. All bricks inside a single cage are expected to be the same liquid cooling technology.

Unified cutout

Open19 V2 liquid cooling implements a unified liquid cooling cutout. This allows for a consistent brick design to implement both liquid cooling solutions. Implementing the unified cutout is not required, provided all the requirements of a single solution are met.

Figure 90. Brick unified cooling cutout

### 5.5.2. Single phase

Single-phase Connector selection

Single-phase cooling solutions shall use the CPC BLQ4 (https://www.cpcworldwide.com/Products/Liquid-Cooling/Everis-BLQ4) family of interfaces.

Figure 91. BLQ4 body for manifold

Figure 92. BLQ4 insert for bricks

BLQ4_SpecSheet.pdf

The BLQ4 connectors are blind mate. Both sides of the connector have G 3/8" threads which thread into manifold (body) and brick (insert), respectively.

Figure 93. BLQ4 pair

Single-phase connector mounting and polarization

Bricks shall have male blind-mate connectors (inserts), BLQ4D47006 or compatible part.

When viewed from the rear of the brick, in reference to the server: Liquid return shall be located to the left. Liquid supply shall be located in the to the right.

Figure 94. Brick side supply and return

Single-phase brick side connector locations

The supply connector should be 29.5mm from the outer side of the brick (opposite the thumbscrew) in the x-direction and 20.7mm from the bottom of face of the brick in the y-direction. THe two connectors should be lined up in the horizontal plane and spaced 28.5mm from each other.

Figure 95. Brick side liquid connector locations for single-phase

Single-phase offset depth

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

Figure 96. Mating surface BLQ4 insert

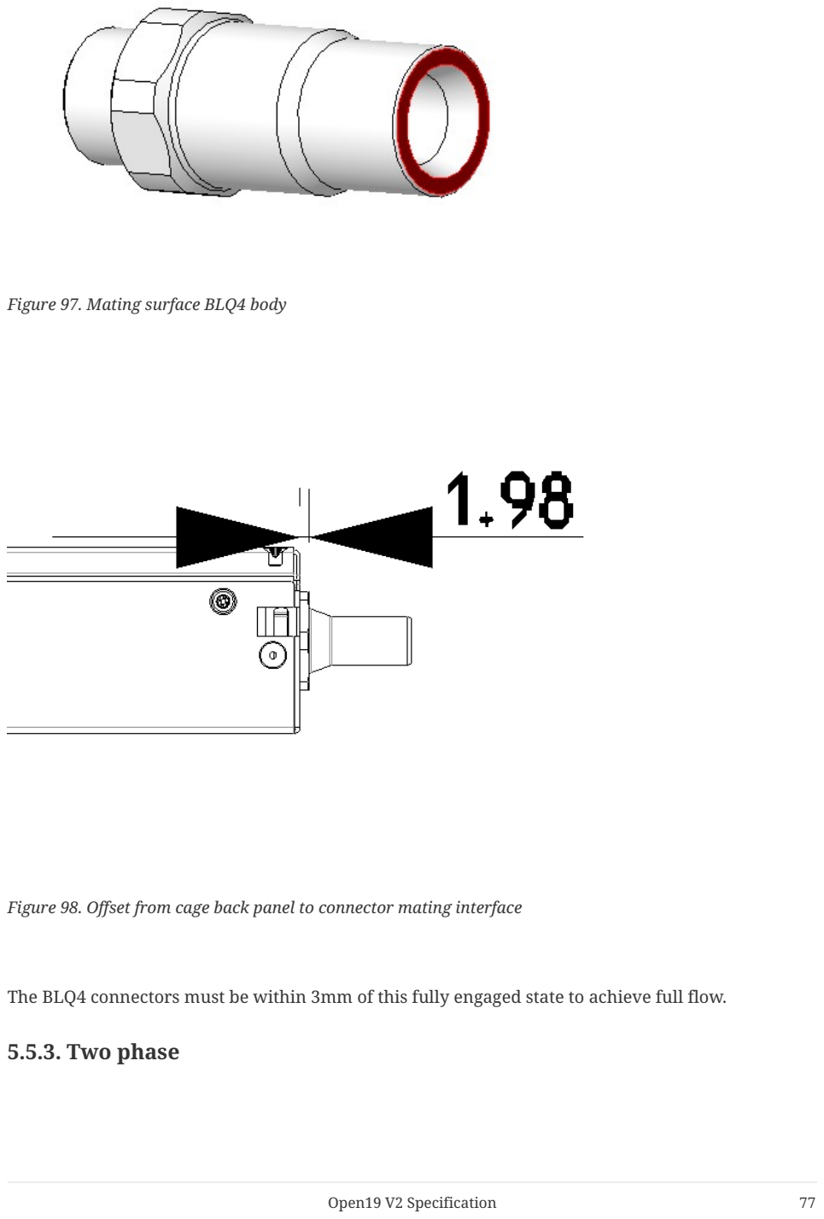
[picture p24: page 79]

Figure 97. Mating surface BLQ4 body

Figure 98. Offset from cage back panel to connector mating interface

The BLQ4 connectors must be within 3mm of this fully engaged state to achieve full flow.

### 5.5.3. Two phase

Two-phase connector selection

The two-phase cooling solution shall use the CPC BLQ family of interfaces.

On brick side

Figure 99. Liquid - CPC BLQ4 series insert P/N BLQ4D47004PROTO (chrome plated brass) or P/N 4649800PROTO (Aluminum)

Figure 100. Vapor - CPC BLQ6 series insert P/N 4650000PROTO (chrome plated brass)

On the Manifold side

Figure 101. Liquid - CPC BLQ4 series body P/N BLQ4D31004PROTO (chrome plated brass) or P/N 4649900PROTO (Aluminum)

Figure 102. Vapor - CPC BLQ6 series body P/N 4650200PROTO (chrome plated brass)

Two-phase connector mounting polarization

Cage manifolds shall have body (female) blind mate connectors. Bricks shall have insert (male) blind-mate connectors. When viewed from rear of the brick, vapor connection shall be located at the right position. Liquid connection shall be located at the left position.

Figure 103. Brick liquid supply and Vapor return

Two-phase brick side connector locations

Using the right-side panel of the brick as a reference, the Vapor return connector on the brick should be 31.85mm in the x direction and 20.73 upwards in the y direction.

Figure 104. Brick side connectors locations

Two-phase offset depth

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


Figure 105. Mating surface BLQ4 insert

Figure 106. Mating surface BLQ4 body

Figure 107. Mating surface BLQ6 insert

Figure 108. Mating surface BLQ6 body

Figure 109. Offset from cage back panel to BLQ4 connector mating interface

Figure 110. Offset from cage back panel to BLQ6 connector mating interface

The BLQ4 & BLQ6 connectors must be within ±1.5mm of this engaged state to achieve full flow.

# 5.6. Design guidance

Design guidance is not a specification requirement. It is simple design guidance that can be implemented to simplify future needs, to meet certification requirements, or satisfy general fit & finish.

### 5.6.1. Brick faceplate guidance

The faceplate is notched above and below the fastener (See Figure 78, “Brick retention”). Note that the faceplate can accommodate any type of ports or drives as needed and is not required to be fully perforated.

Screws and/or rivets used to secure the top cover are flush to be under-flush. The vertical edges on the rear of the brick chassis base are coined to break sharp edges.

### 5.6.2. Back panel safety perforation

See below for typical dimensions of the airflow perforation. All dimensions below are critical.

Figure 111. Brick panel perforation

Keep-out zones

Keep-out zones are defined in the brick surrounding the power connector and liquid cooling interfaces. The liquid cooling keep-out spaces "fly" above the PCB, allowing components to be populated below the connections.

Figure 112. Brick keep-out zone

Figure 113. Brick keep-out zone top view

# 5.7. Brick performance

### 5.7.1. Brick electrical startup behavior

In order to safely operate the power shelf, we define the following characteristics for brick startup behavior.

Figure 114. Server startup electrical characteristics

These values are per connector feed from a power shelf.

Two power connectors are available for use.

- Min start-up voltage: +44V DC
- Max input capacitance per brick feed: ⇐1000uF
- Max server current at start-up voltage: 70A
- Ramp time: Follow Intel CRPS spec: ramp time 10-70msec, slew rate 0.5V/msec

https://www.intel.com/content/dam/www/public/us/en/documents/guides/power-supply-design-guide-june.pdf (https://www.intel.com/content/dam/www/public/us/en/documents/guides/power-supply-design-guide-june.pdf)

# Chapter 6. Brick Mechanical Specification [DHDW]

# 6.1. DHDW Brick

The DHDW brick is commonly used as a 2U server form-factor.

# 6.2. Brick Dimensions

The brick is designed with the overall dimensions shown.

Figure 115. Brick dimensions

Please refer to the drawings, and 3D files for further details.

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

# 6.3. Mechanical features

### 6.3.1. Brick retention

The brick is secured into the cage with up to four Southco D9-47-1302-K quarter-turn fasteners, located on the left and right side of the faceplate.

Figure 116. Brick retention

### 6.3.2. Brick mechanical guide

Clearance channels are required along the top edges of the brick and the sidewalls, extending forward from the rear panel to the back of the faceplate.


Figure 117. Mechanical guide at top edge and side walls of brick

Brick insertion and retention assistance for liquid cooling

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

The features are:

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

Figure 118. Brick mechanical assistance features in cage

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

### 6.3.3. Brick Mechanical Keying

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

Figure 119. Brick keying

Figure 120. Brick keying dimensions

### 6.3.4. PCBA

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

Figure 121. PCBA References

Figure 122. Brick PCB dimensions

### 6.3.5. Materials

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

### 6.3.6. Blind mate interfaces

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

The power connector has two ratings:

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

The brick may populate up to four sets of connectors, as required.

### 6.3.7. Weight

The maximum weight of the brick, when equipped with all drives and/or accessories, is 120lbs (54.43kg). This is an increase of 20lbs from V1.

# 6.4. Connector Pinout

### 6.4.1. Brick power connector

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

Two variations of the brick connector exist, with different Not-to-exceed (NTE) ratings:

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


Figure 123. Power connector supply/return definition

Figure 124. Power connector footprint definition

Connector drawings are available: Molex Brick power connector

### 6.4.2. Brick critical dimensions

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

Figure 125. Power connector critical dimensions

### 6.4.3. Brick voltage

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

- Operating range: 48-52V
- NTE voltage: 54V
- Max voltage: ⇐52.5V for <200mS

### 6.4.4. Data Connector

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

Figure 126. Impel Connector with guide feature

Figure 127. Impel Mated connector with cable backshell

The data connector pinout is defined in the [Appendix]

There is no attempt to support 50G (2x25G NRZ) nor 50G (1x50G NRZ).

### 6.4.5. Ethernet interface inter-operability

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

# 6.5. Liquid cooling
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

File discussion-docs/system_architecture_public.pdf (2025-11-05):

# Open19 System Specification

### Linux Foundation Sustainable Scalable Infrastructure Alliance

# Table of Contents

Open19 V2 Specification | 1

# Open19 V2 Authors/Contributors

ASRock Rack: Weishi Sa

Cisco: Christopher Liljenstolpe

CoolIT: Brandon Peterson

Delta: Ralf Pieper

Equinix: Doug Asay, Suresh Pichai, My D. Truong

Inspur: John Leung, Kay Lu

Molex: Liz Hardin, Keegan McGraw, Chuck Crandley, Jeff Joniak

SE: Erin Mccann, Rob Bunger

Vertiv: Roy Grantham

ZutaCore: Shahar Belkin, Or Farjun

2 | FOR PUBLIC DISTRIBUTION


The Sustainable & Scalable Infrastructure Alliance (SSIA) is a community-based organization dedicated to creating, fostering and driving adoption of open standards that increase the efficiencies of the data center and digital infrastructure supply chains. We enable digital leaders from any sized organization to adopt and deploy advanced and highly efficient rack-level datacenter technologies to increase sustainability, power next-generation workloads and reduce cost and waste, regardless of deployment size or location.

SSIA members include data center operators, private and public cloud end users, supply chain manufacturers and technology component providers, as well as thousands of individual members active in the cloud, technology, data center and edge ecosystem.

Learn more about joining the Linux Foundation SSI Alliance at http://www.ssia.org/about-us/.

# Chapter 1. Change log

Author | Date | Version | Change Details
My Truong | Nov 2023 | 2.0 | Public Spec release

# Definitions

ASHRAE
American Society of Heating, Refrigerating and Air-Conditioning Engineers

ASHRAE W27
ASHRAE specification for water temperature range from 2 °C to 27 °C

OCP
Open Compute Project

SFP
SNIA SFF-8402 SFP+ 1X Pluggable Transceiver Solution

SNIA
Storage Networking Industry Association

QSFP
SNIA SFF-8679 QSFP+ 4X Pluggable Transceiver Solution

QSFP-DD
QSFP-DD MSA QSFP DOUBLE DENSITY 8X AND QSFP 4X PLUGGABLE TRANSCEIVERS

# Chapter 2. Open19 V2 Cages

Open19 V1 defined a base building element, the brick cage, for building the Open19 infrastructure. The cage is a completely passive element able to receive any Open19 V2 compliant device. The brick definition governs cage dimensions (and visa versa). The cages are re-configurable to accommodate any Open19 V2 compliant brick.

Open19 V2 introduces cut-outs and attachment features for liquid cooling manifolds, expanded cutout for the larger blind-mate data connector, and expanded cut-out for the new power connector.

# 2.1. Cage modularity

Cages are designed to support all defined bricks. The current definition of bricks use a 2RU maximum format, enabling the following brick form-factors in each 2RU section:

- (4) Single high Brick - Half-width 1RU [SHHW]
- (2) Double high bricks - Half-width 2RU [DHHW]
- (2) Single high bricks - double-width 1RU [SHDW]
- (1) Double high brick - double-width 2RU [DHDW]

The design package supports two cage form-factors, 8RU and 4RU. Additional cage groupings can be synthetically formed from these units, including the 12RU from the V1 spec. This enables extremely small deployments of 6RU (4RU cage + 2RU power shelf) with no upper limit.


Figure 1. 8RU Open19 V2 cage front

# 2.2. 8RU Cage detail

The 8RU cage is designed to be installed in a standard EIA/TIA 19-inch rack. The dimensions of cage allow for proper mating of all blind-mate interfaces on bricks.

### 2.2.1. 8RU Cage dimensions


Figure 2. 8RU Open19 V2 cage depth


Figure 3. 8RU Open19 V2 cage depth side view


Figure 4. 8RU Open19 V2 cage rear

### 2.2.2. 8RU Cage partition

The 8RU cage is built around a 2RU section, 84.7±0.25mm tall and 443.80±0.25mm wide. This section can accommodate a single DHDW brick or two SHDW bricks.

### 2.2.3. 8RU Cage Center divider (CD) partition

With a center divider (CD) installed, each section can accommodate one of the following combinations:

- One to four SHHW bricks
- One or two DHHW bricks

Dropped from the V2 spec is one DHHW plus one or two SHHW bricks.

With the center divider installed, each 2RU section is 84.7±0.25mm tall and 215.02±0.25mm.

### 2.2.4. 8RU Cage Center Divider (CD)

The Center Dividier (CD) is installed to support SHHW and DHHW bricks. Mechanical retention of


the divider should be integrated into the divider. The Open19 V1 specification provides details on a reference CD design.

Figure 5. Open19 V2 cage Center Divider

### 2.2.5. Horizontal divider

The horizontal divider partitions the cage in 2RU sections. Horizontal dividers shall have strips to provide a low-friction surface and minimize metal-on-metal contact.

Figure 6. Open19 Cage horizontal divider

### 2.2.6. Load capacity

The 8RU cage can accommodate 16 bricks with a maximum 30lbs (13.6kg) each.

### 2.2.7. Brick Retention

Each side wall contains eight (8) Southco D9-63-11 self-clinching receptacles that secure bricks with quarter-turn fasteners as the primary means of retention.


Figure 7. Cage retention quarter turn fastener locations

For liquid cooling applications, additional features are available to provide sufficient mechanical assistance to overcome total connector forces. These features are detailed in the liquid cooling section.

### 2.2.8. Blind mate cutouts

The rear wall of the 2RU space provides consistent cutouts for the cooling, data, and +48V DC power cables.


Figure 8. Cage rear panel cutouts


Figure 9. Cage rear panel cutout details

### 2.2.9. Keying stops

Keying stops are provided in the right and left rear corners of each cage section. These stops (bent tabs) interface with notches in the brick sides to provide a positive stop during brick insertion and prevent over insertion or possible connector damage. They are positioned as shown.


Figure 10. Brick keying stops
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

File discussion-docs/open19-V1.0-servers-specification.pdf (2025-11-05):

Open19 Foundation Copyright © 2018 | Page 1

# Open19 Server Specification

## Yuval Bachar LinkedIn

## Document Number: O19-1000-0002

Version Tracking

Author | Date | Version | Change details
Yuval Bachar | 3/11/2019 | 1.0 | Release version

Legal Disclaimer
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

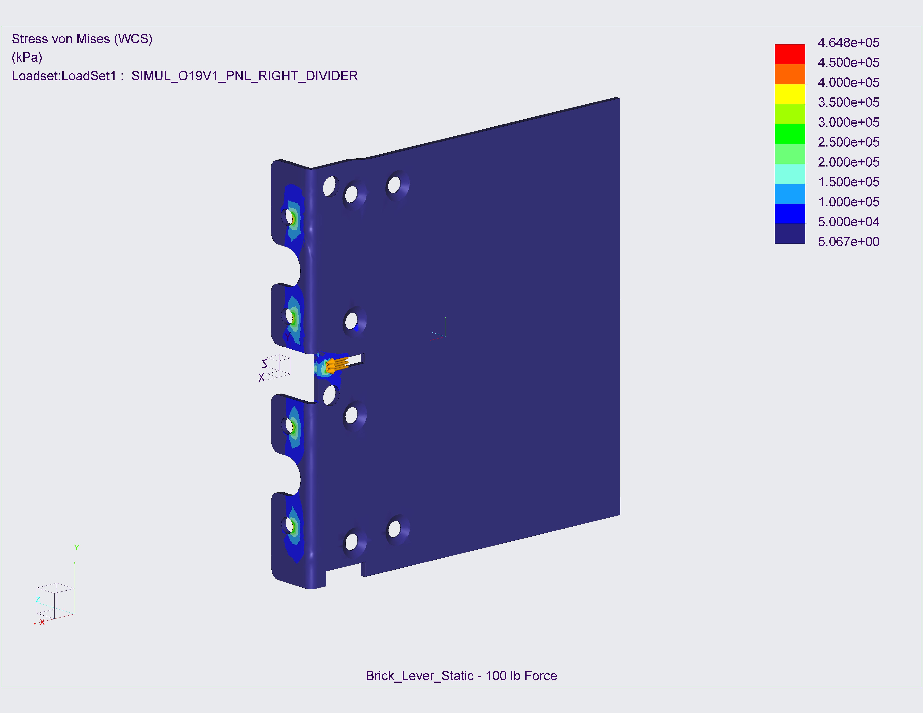
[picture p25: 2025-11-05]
images/chapters/ch_system_architecture/Open19_V2_Ctr_Divider_Brick_Lever_Forces.jpg

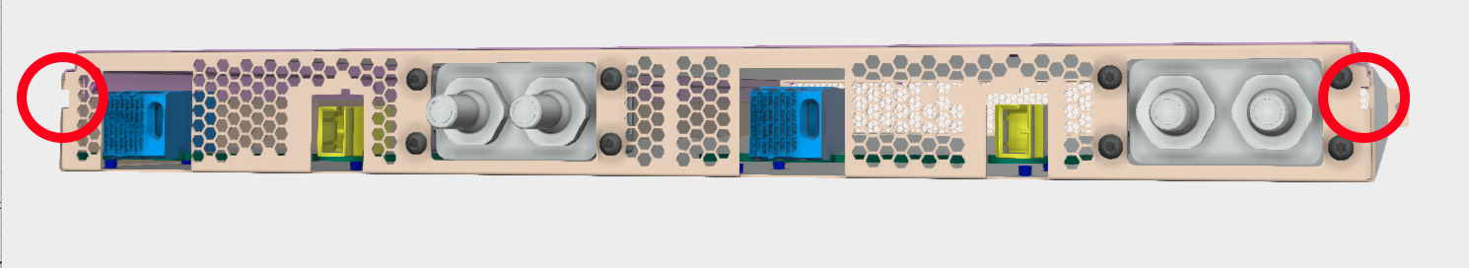
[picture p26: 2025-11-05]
images/chapters/ch_brick_mechanical/shdw_brick_mechanical_stop.png

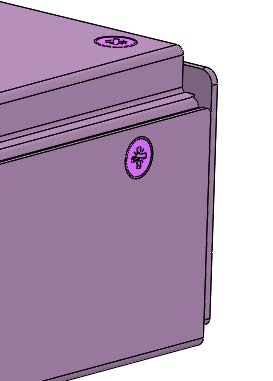
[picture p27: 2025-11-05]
images/Figure 23 - Double Wide Brick Design Consideration 3D.jpg

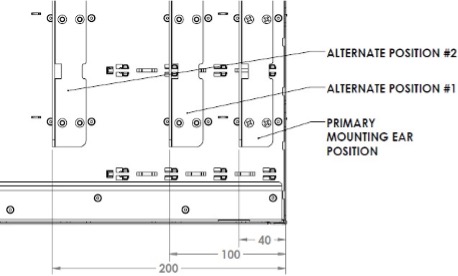
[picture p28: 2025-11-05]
images/chapters/ch_system_architecture/mounting_ear_positions.jpg

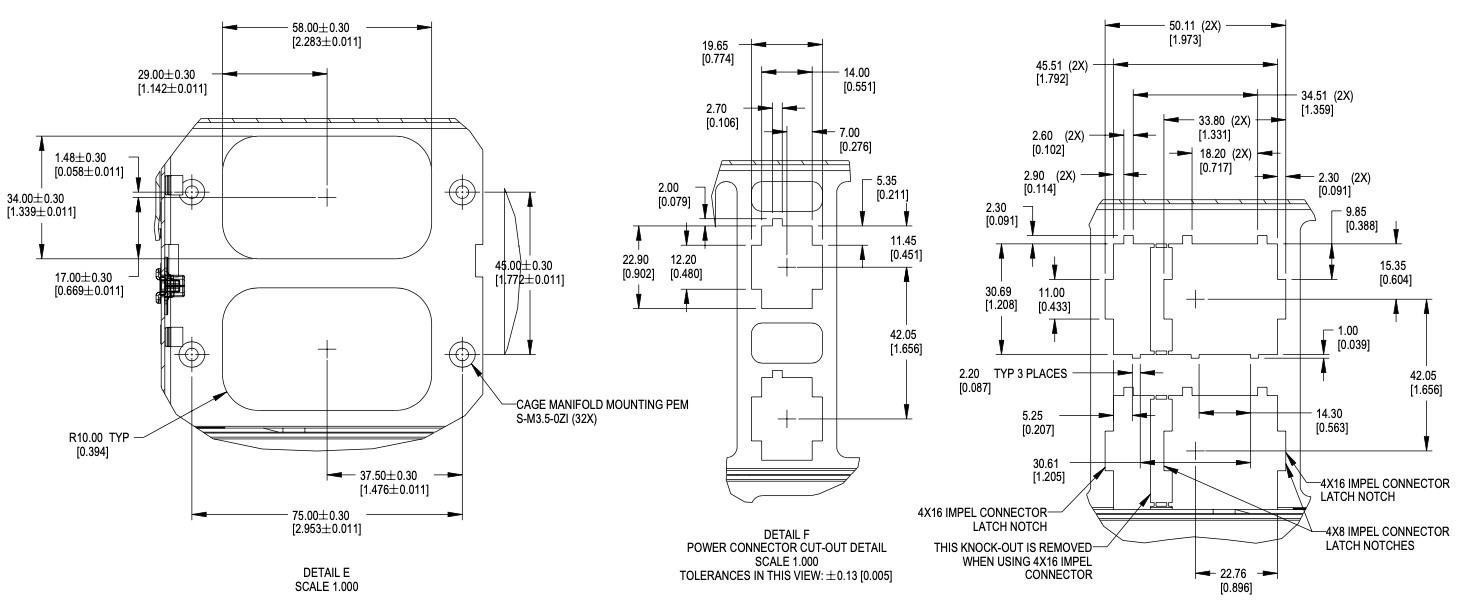
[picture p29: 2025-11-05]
images/chapters/ch_system_architecture/cagecutoutsdetail.png

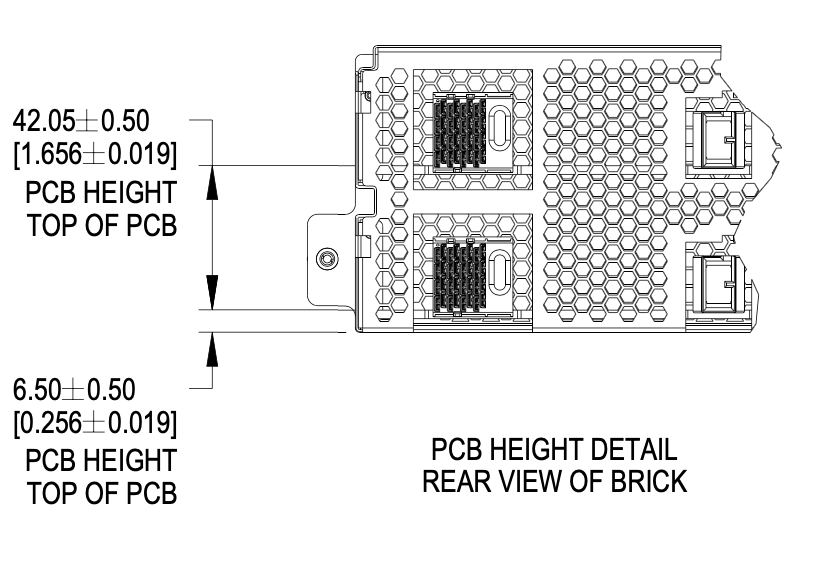
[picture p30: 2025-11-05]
images/chapters/ch_brick_mechanical/dhhw_brick_pcb_references.png

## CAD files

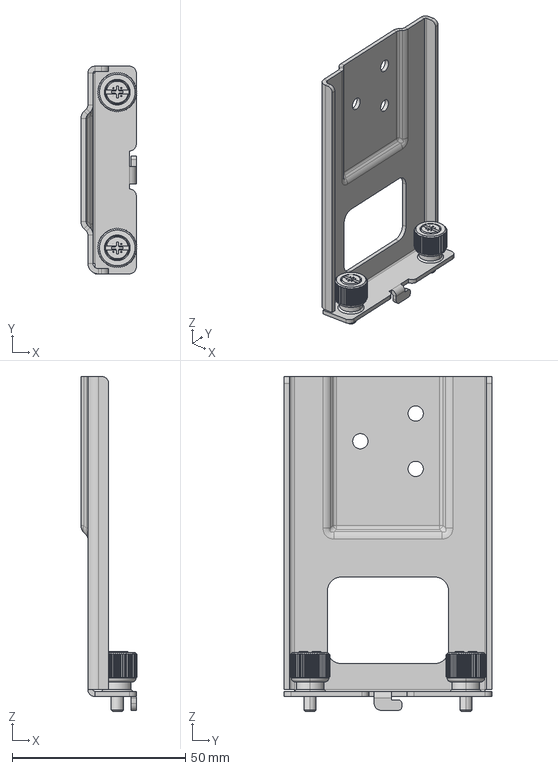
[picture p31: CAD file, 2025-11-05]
mechanical/manifold_bracket/O19V2_2PH_BRKT_CAGE_MNFLD_LH.stp
16.2 x 60.0 x 96.8 mm
O19V2_BRKT_MTG_CAGE_MNFLD_LH
SCREW_CAPTIVE_PF11-M3_5-0_CLSD x 2

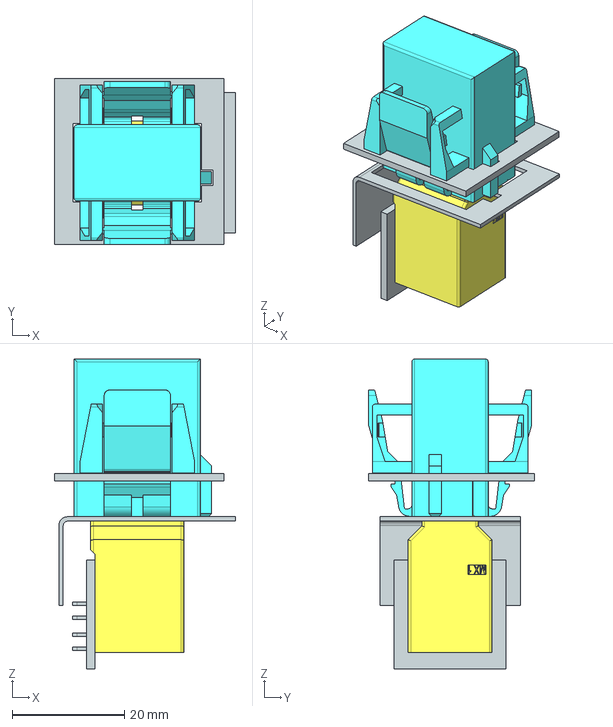
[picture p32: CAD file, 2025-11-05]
power/brick_power_connection_with_panel_with_key_and_updated_panel.stp
32.3 x 29.5 x 55.2 mm
4000387693pdm000_01
4000387685pdm000_01

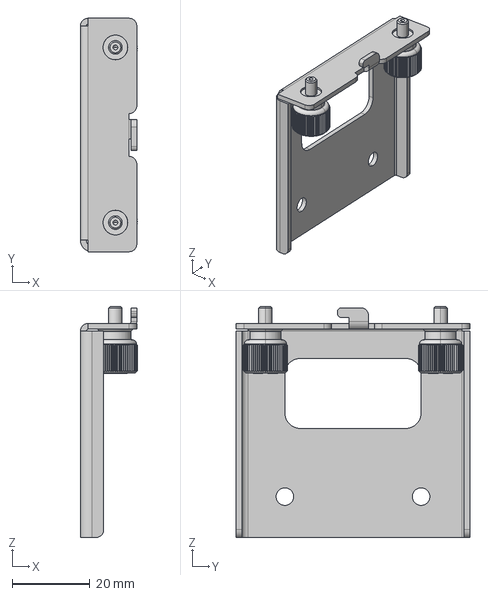
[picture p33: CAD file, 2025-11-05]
mechanical/manifold_bracket/O19V2_1PH_BRKT_CAGE_MNFLD_LH.stp
14.7 x 60.0 x 59.3 mm
O19V2_SE_BRKT_MNFLD_CAGE_LH
SCREW_CAPTIVE_PF11-M3_5-0_CLSD x 2

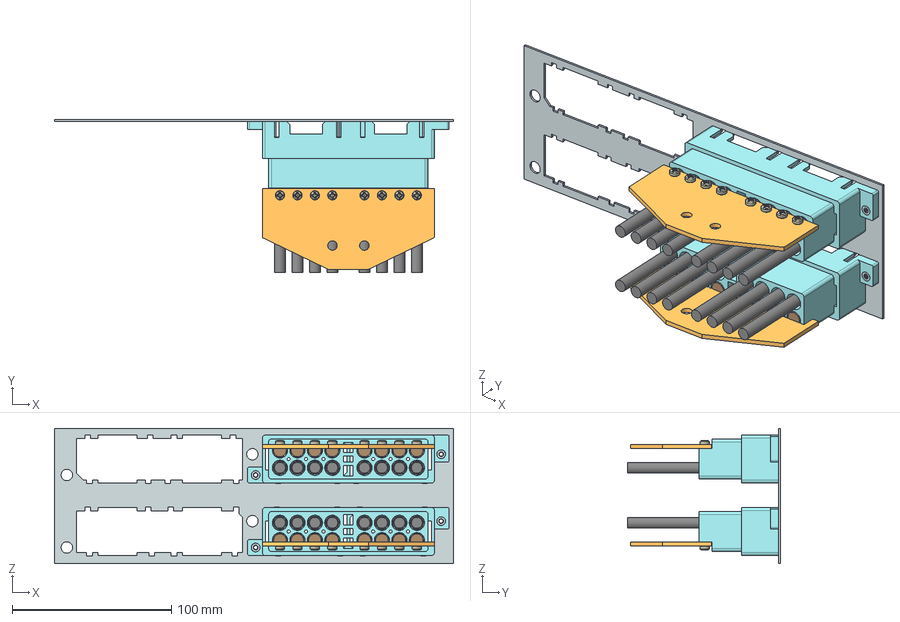
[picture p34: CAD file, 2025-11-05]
power/power_shelf_connector__with_panel.stp
250.2 x 96.1 x 84.7 mm
2203660001pdm000_01
2057700001pdm000_02 x 4
4000390052pdm000_01 x 2
2155122004pdm000_02 x 16
2046090637pdm000_01 x 16
2046101034pdm000_05 x 32
2043600008pdm000_03 x 32
2046090634pdm000_01 x 16
2203680000-wirepdm000_01 x 16
2203660000pdm000_01

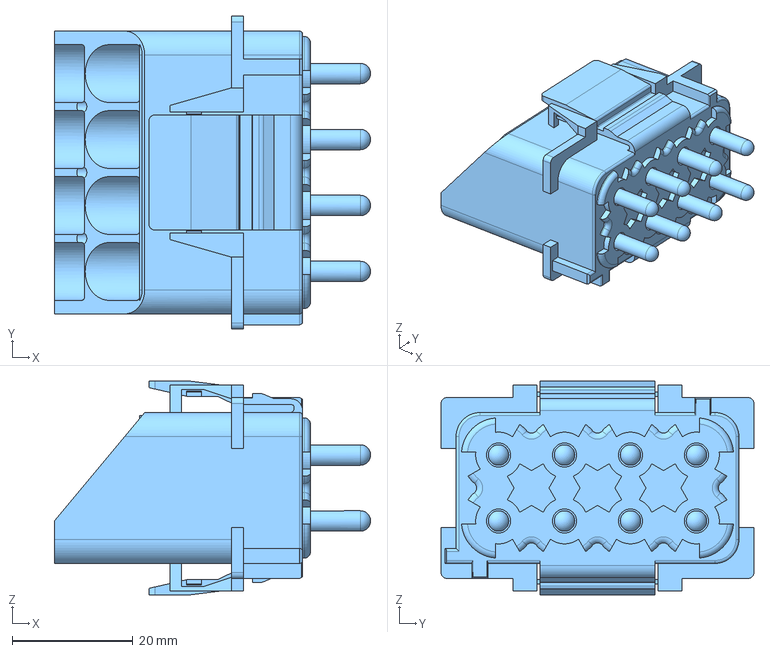
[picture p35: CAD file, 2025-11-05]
power/power_shelf_to_cable_connectors/2203670005-cmpdm000_01.stp
52.5 x 52.0 x 35.5 mm

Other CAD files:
mechanical/manifold_bracket/O19V2_2PH_BRKT_CAGE_MNFLD_RH.stp
mechanical/manifold_bracket/O19V2_1PH_BRKT_CAGE_MNFLD_RH.stp
power/power_shelf_to_cable_connectors/2203670006-cmpdm000_01.stp
power/power_shelf_to_cable_connectors/2203670004-cmpdm000_01.stp
power/power_shelf_to_cable_connectors/2203670002-cmpdm000_01.stp
power/power_shelf_to_cable_connectors/2203670003-cmpdm000_01.stp
power/power_shelf_to_cable_connectors/2203670001-cmpdm000_01.stp
power/power_shelf_to_cable_connectors/2203670007-cmpdm000_01.stp
power/power_shelf_to_cable_connectors/2203670008-cmpdm000_01.stp

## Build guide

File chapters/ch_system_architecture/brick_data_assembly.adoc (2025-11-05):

= Open19 data cable assembly

Open19 V2 relaxes the data cable requirements and has moved the cables into implementation specific designs. The brick data connector provides definitions for all pins and usage, in order to enable interoperability for all brick designs. 

The data cable shall provide, as needed, the EEPROM required for SFP, QSFP, and QSFP-DD connectors.

== SFP breakout implementation

The SFP28 breakout implementation supports four (4) SFP28 connections from each brick connector.

[#img-sfp-cable]
.SFP28 breakout cable



{sp} +

[#img-cage-impel-attachment]
.Cage Impel attachment



{sp} +

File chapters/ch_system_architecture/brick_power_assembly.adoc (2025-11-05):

= Open19 Power Cabling

The Open19 V2 power distribution cabling groups each half-cage (1/2 wide 1U) into a power connector on the power shelf. Each assembly is intended for a single cage. The V2 specification relaxes the requirement on the location of the power shelf and moves the assembly definition to an implementation guide. With the shift to +48V DC power, the signal integrity on the data cable at 50G-PAM4 typically provides implementation constraints. Power cable assemblies are expected to be longer with more variations than the V1 specification.

Each cabling system is built for 8-channel aggregation. Each bundle is an array of power distribution cables (supply and return) and carries +48V DC (+51V nominal) to the bricks. Power shelf connectors are rated to carry 70A. Brick connectors may carry 35A or 70A. Cables shall be sized appropriately to handle the current and length. 

== Open19 Power shelf connector

Power shelves may implement any power connector that meets brick power requirements and brick inter-operability. The Open19 community has developed a power shelf connector set utilizing the Molex Coeur Socket (tm). Any power harness mating to the Couers Socket and Ten60 blade connector shall use the following design. Power shelf designs that do NOT implement the Coeur Socket, or interoperable connector, may propose alternate designs for inclusion to the specification. Brick connectors shall always interop with the 70A Ten60 blade connector.

=== Power shelf connector

The power shelf connector is a 70A rated assembly. It shall be used for all implementations 70A and less per power feed to bricks. A detect pin is used to indicate the type of assembly connected to the the power shelf.

[#image-power-shelf-connector]
.Power shelf connector



{sp} +

[#image-power-connector-in-panel-upper]
.Power shelf connector mounted in panel, upper view



{sp} +

[#image-power-connector-in-panel-lower]
.Power shelf connector mounted in panel, lower view



{sp} +

ifdef::private[]

=== Power shelf connector pinout

:leveloffset: +3

include::../../power/power_shelf_2RU_connector_pinout.adoc[]

[#image-2RU-power-shelf-connector-pinout]
.2RU Power shelf connector pinout



{sp} +

:leveloffset: -3

endif::[]

=== Power shelf universal input connectors

The power shelf shall use input connectors common to OCP Open Rack V3. Refer to the link:https://www.opencompute.org/documents/ocp-spec-v1-0-orv3-power-shelf-universal-input-power-connector-pdf[Open Rack V3 Shelf AC Input connector V1.0] for detailed information.

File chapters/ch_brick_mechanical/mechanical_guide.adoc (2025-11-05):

ifndef::imagesdir[:imagesdir: ../../images]
ifndef::brick[:brick: brick]
ifndef::UBrick[:UBrick: Brick]
ifndef::brickplus[:brickplus: brick]
ifndef::bricktype[:bricktype: shhw]

= {Ubrick} mechanical guide

ifdef::shhw,shdw[]
Clearance channels are required along the top edges of the brick, extending forward from the rear panel to the back of the faceplate.
endif::[]

ifdef::dhhw,dhdw[]
Clearance channels are required along the top edges of the brick and the sidewalls, extending forward from the rear panel to the back of the faceplate.
endif::[]

ifdef::shhw,shdw[]
[#image-{bricktype}_Mechanical_Guide]
.Mechanical guide at top edge of brick



{sp} +

endif::[]
ifdef::dhhw,dhdw[]
[#image-{bricktype}_Mechanical_Guide]
.Mechanical guide at top edge and side walls of brick



{sp} +

endif::[]

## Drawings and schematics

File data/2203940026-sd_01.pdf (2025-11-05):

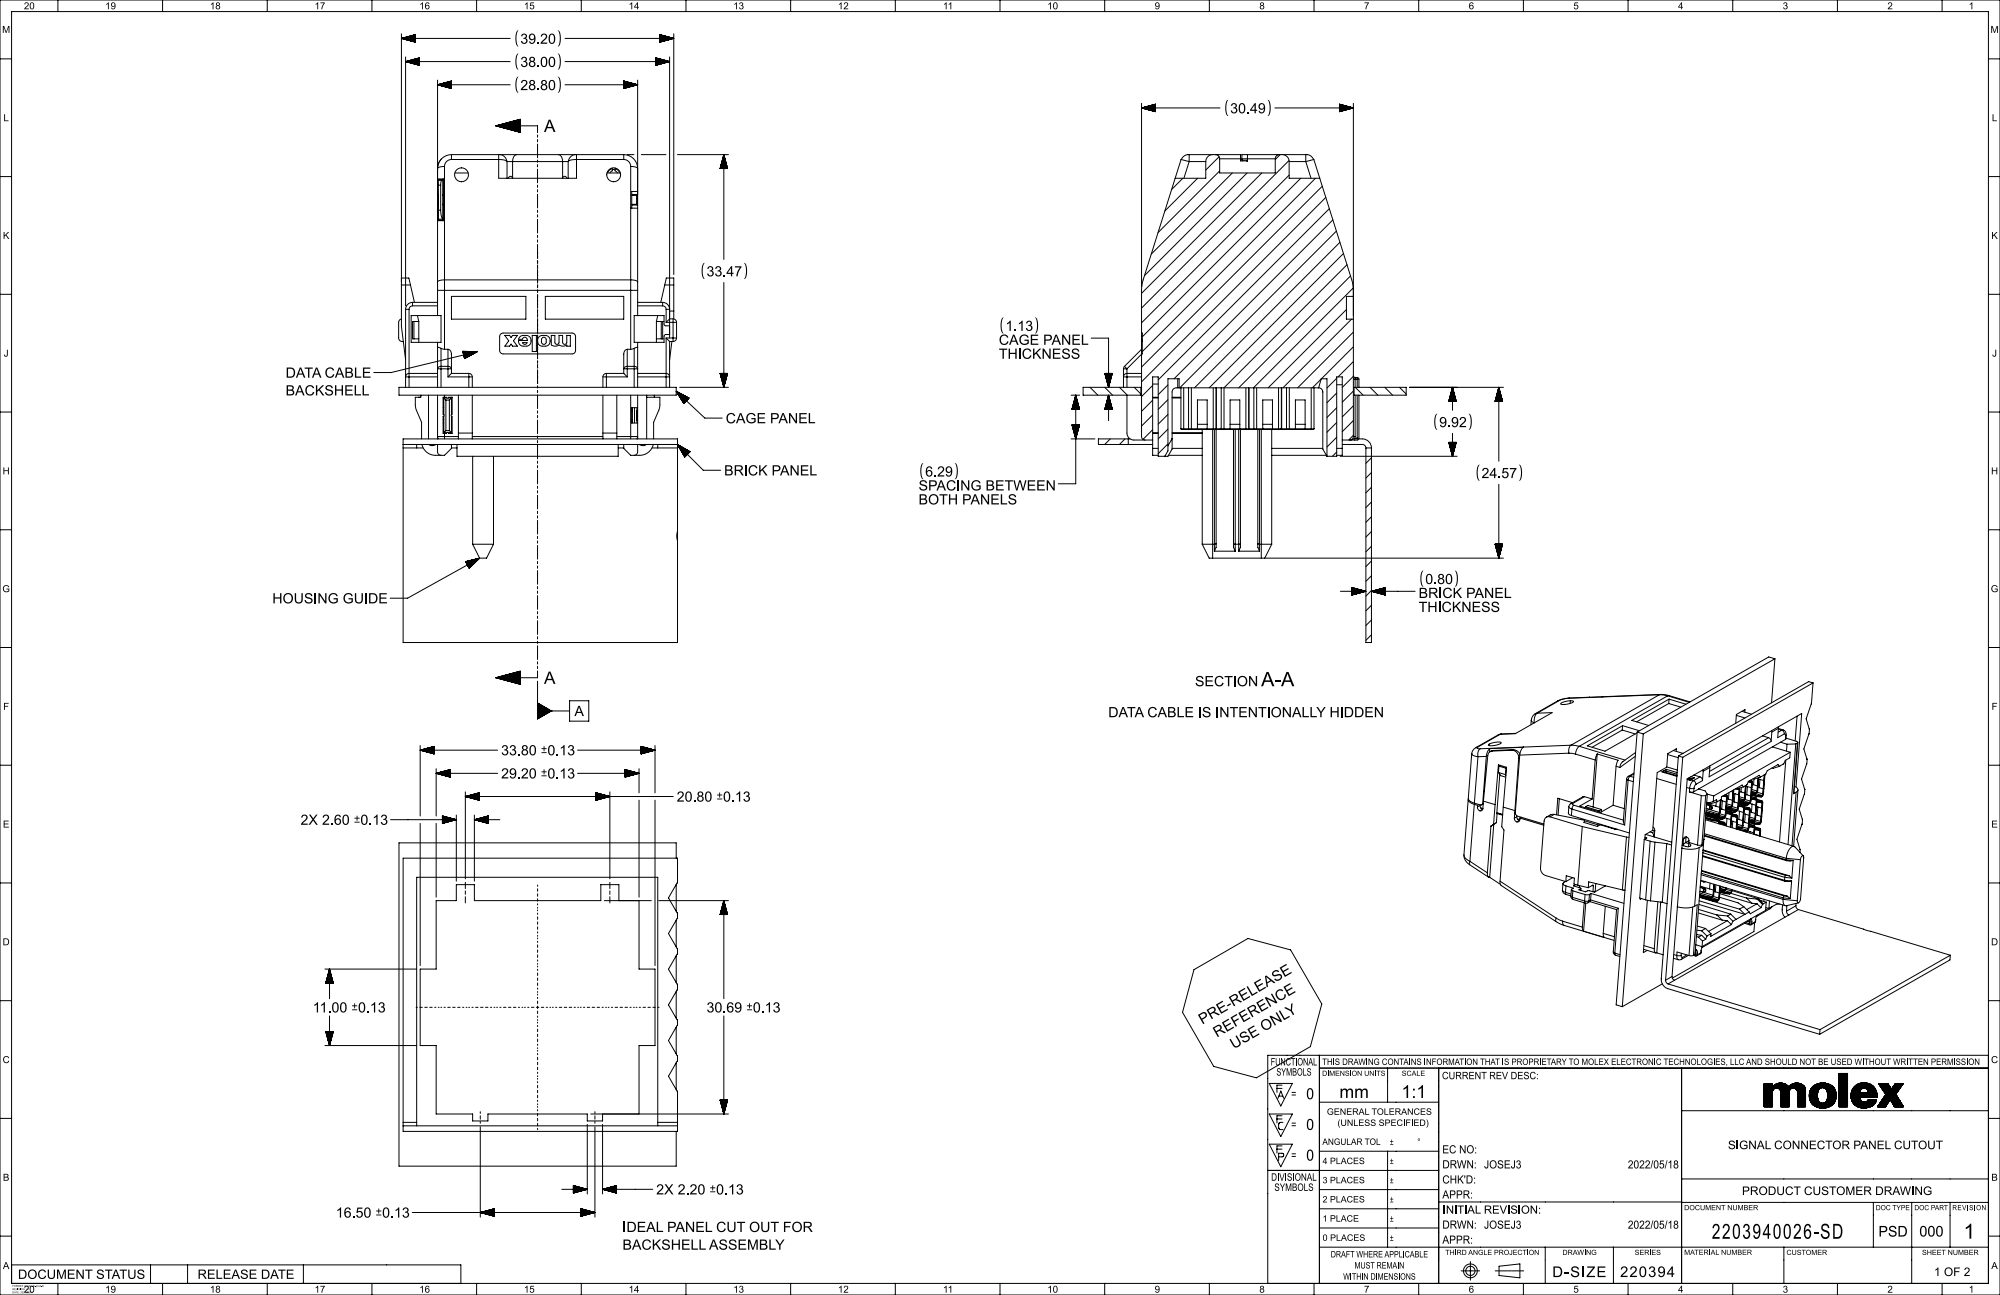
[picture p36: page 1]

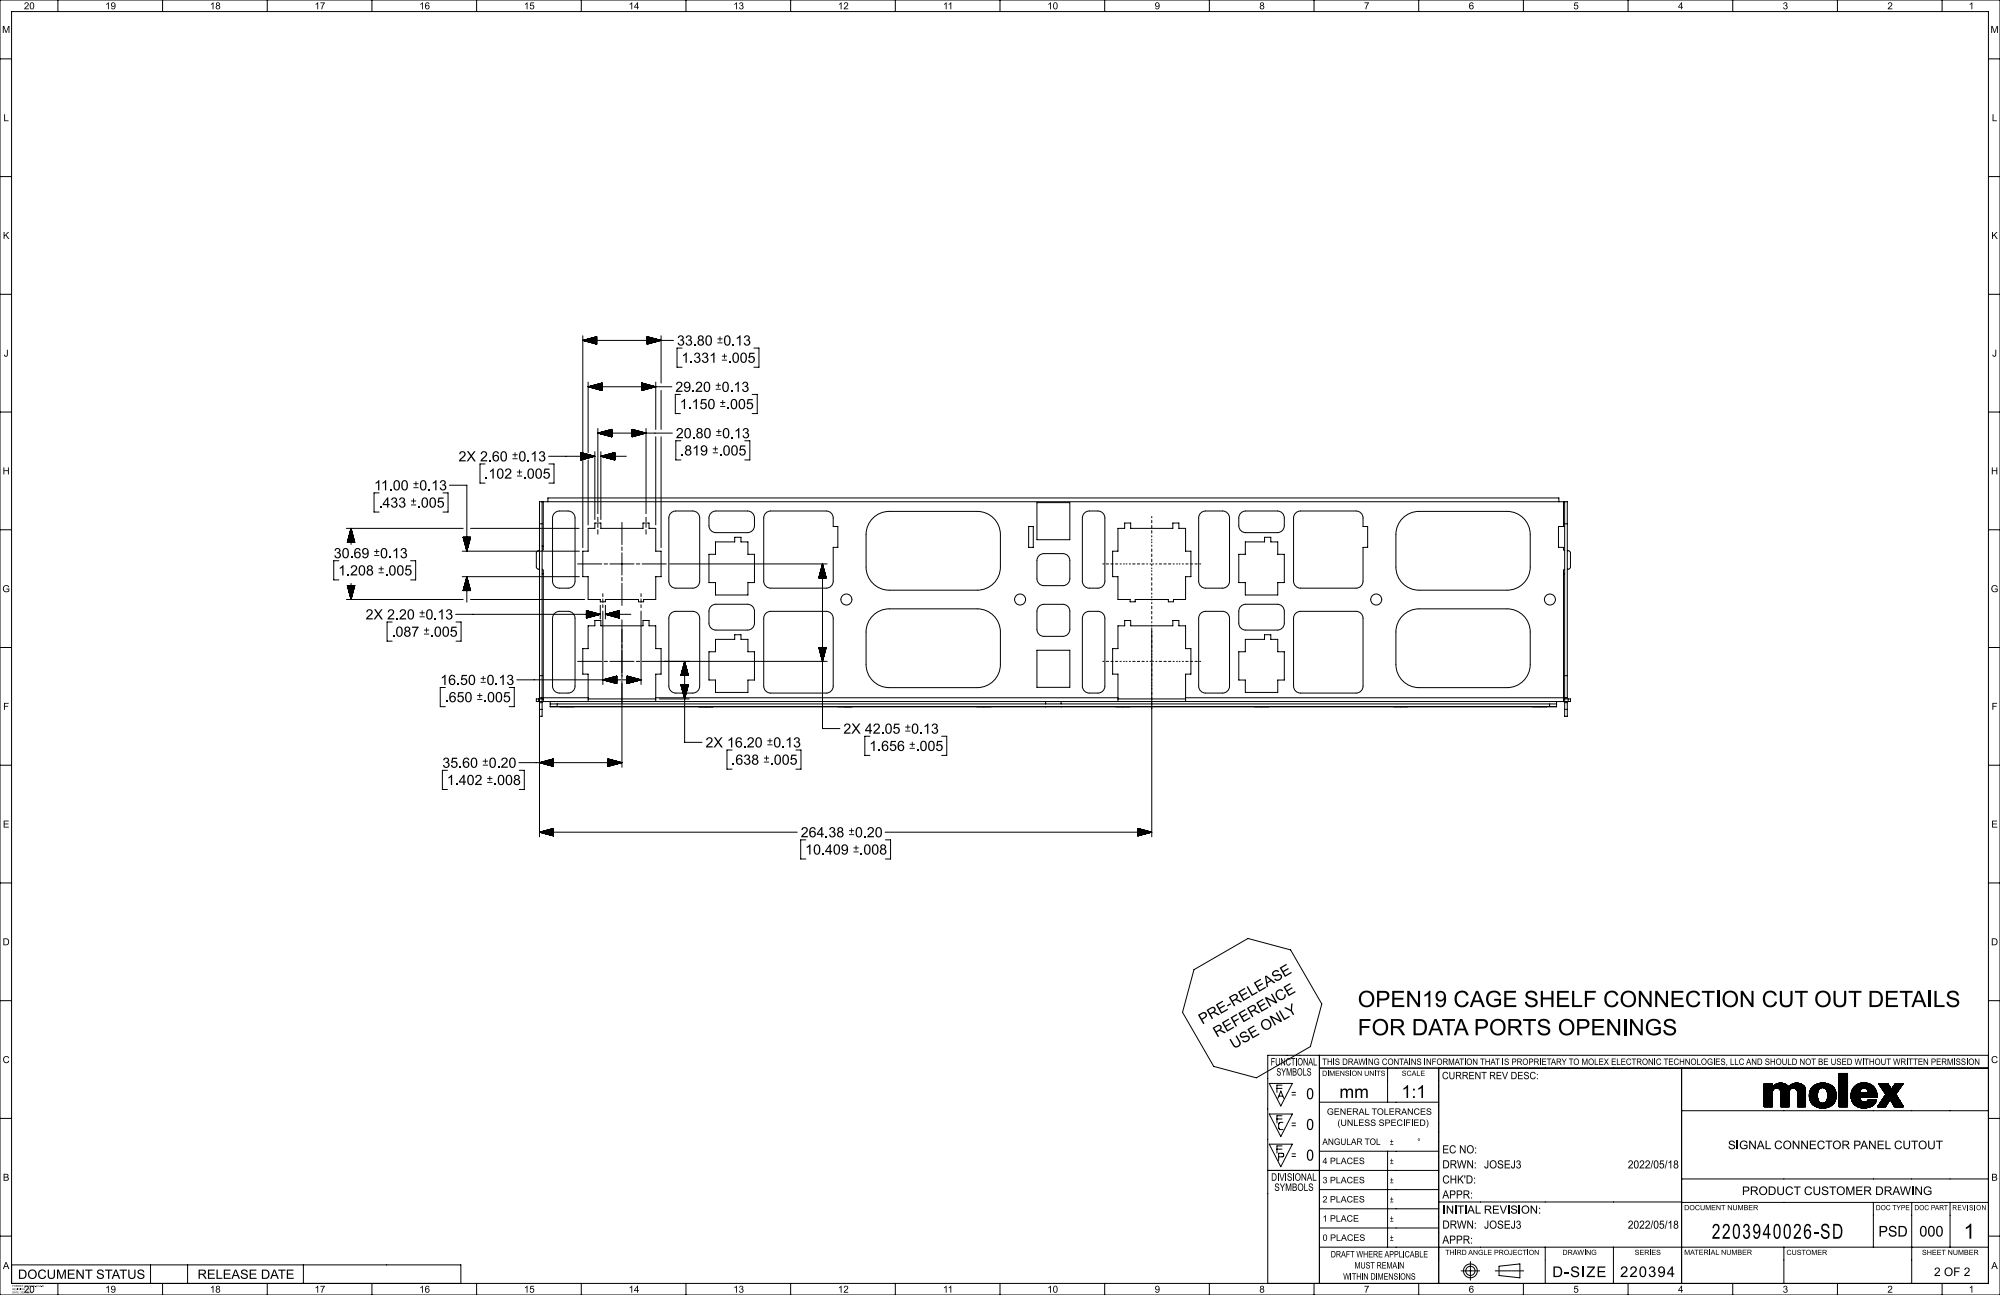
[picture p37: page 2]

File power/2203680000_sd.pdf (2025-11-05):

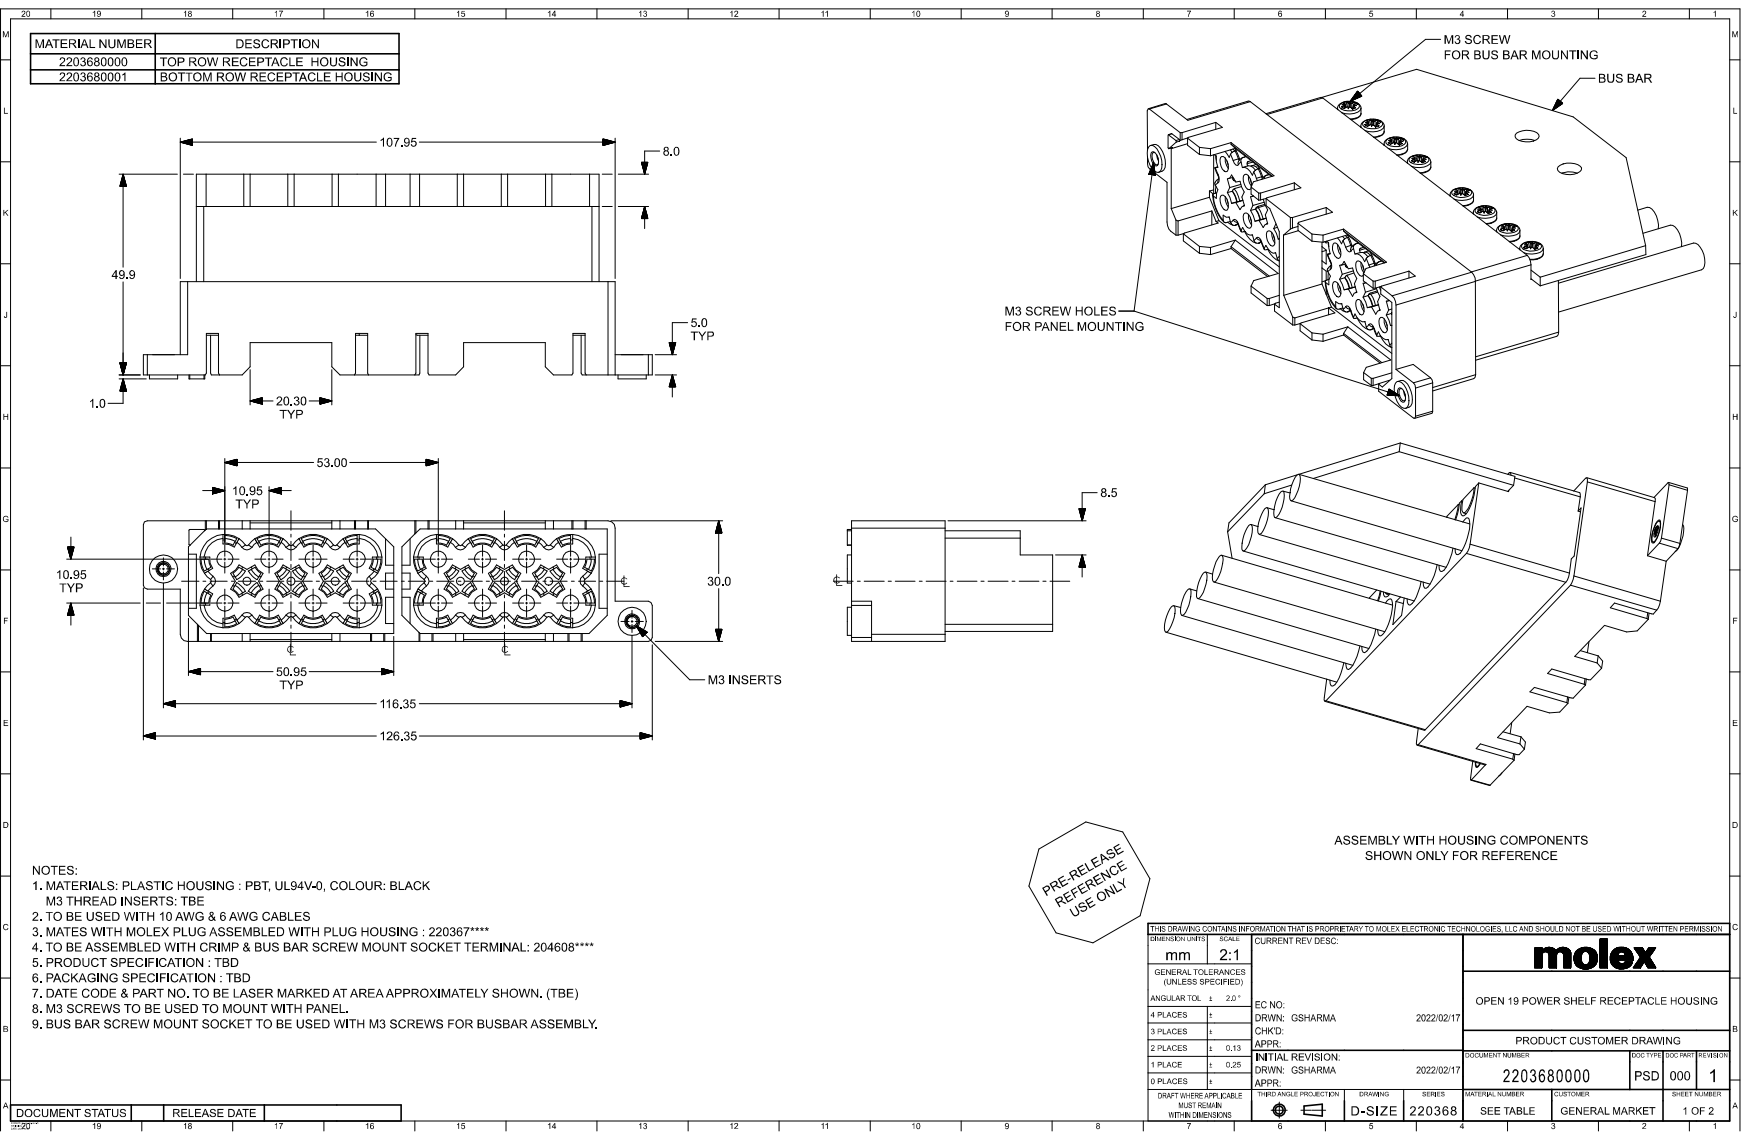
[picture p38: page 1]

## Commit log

2025-10-21 Revise Open19 Server Specification with brick details
    Updated the Open19 Server Specification document to include detailed specifications for various brick types, including dimensions, PCBA details, interconnects, and materials.
2025-10-22 Update print statement from 'Hello' to 'Goodbye'
2025-11-05 Enhance README with detailed Open19 specification features
    Expanded the README to include detailed sections on key aspects of the Open19 specification, including brick form factors, power, networking, cooling, and flexibility.
2025-11-05 Revise README for Open19 V2 specification updates
    Updated the README to reflect changes in the Open19 V2 specification, including new sections on power, networking, cooling, and flexibility.
